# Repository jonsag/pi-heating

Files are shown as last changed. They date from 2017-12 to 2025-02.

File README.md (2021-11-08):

# pi-heating

Some scripts tweaked from https://github.com/JeffreyPowell, and many others created by me.  

Also there are CAD drawings and PCB layouts to build the electrical parts.  

Eventually you will have a Raspberry Pi that:

* controls (for example) a heater
* measures and logs your electric power consumption
* measures and logs numerous temperatures
* measures and logs wind direction and speed
* measures and logs rain
* presents it all via web GUI with some nice graphs
* also presents it on LCD displays
* can export logs to (spreadsheet or) csv

Let's start it all by

## Installing OS

Download 'Raspberry Pi OS Lite' from [https://www.raspberrypi.com/software/operating-systems/](https://www.raspberrypi.com/software/operating-systems/)  

Cd to where your download is and unpack it  
>$ unzip *-raspios-buster-armhf-lite.zip  

Insert SD-card and find out drive letter  
>$ dmesg  

For example /dev/mmcblk0 or /dev/sdb  

Unmount if mounted  
>$ umount /dev/mmcblk0p1  

Write image to SD-card  
>$ sudo dd bs=4M if=<version\>-raspios-buster-armhf-lite.img of=/dev/<device\> conv=fsync status=progress  

    1870659584 bytes (1,9 GB, 1,7 GiB) copied, 105 s, 17,8 MB/s  
    447+0 records in  
    447+0 records out  
    1874853888 bytes (1,9 GB, 1,7 GiB) copied, 139,716 s, 13,4 MB/s  

Remove SD-card and insert it again to make new partitions visible  

Mount the first partition  
>$ sudo mount /dev/<device\>1 /mnt/tmp  

Write empty file to boot partition to enable ssh at boot  
>$ sudo touch /mnt/tmp/ssh  

Remove SD-card and insert it in a RPi connected to your local network and boot it up  

## RPi configuration

### How to find RPi's IP

If you can't locate the IP, here's a little tutorial  

First find your subnet  
>$ ip -o -f inet addr show | awk '/scope global/ {print $4}'  

You will get something like  

    192.168.10.39/24  

where the first of is your ip, and the second is the netmask  

Now scan your local network for hosts  
>$ nmap -snP 192.168.10.0/24  

where the first is your subnet, and the last is the netmask  
Try to figure out which is your RPi from the output  

### How to connect without ssh password (optional)

If you haven't already, create a keypair  
>$ ssh-keygen ~/.ssh/id_rsa  

Copy the public key to RPi  
>$ ssh-copy-id -i ~/.ssh/id_rsa.pub pi@<IP\>  

### Connect and configure

>$ ssh <IP\> -l pi  

Login with user: pi and password:raspberry  

Update  
>$ sudo apt-get update && sudo apt-get upgrade && sudo apt autoremove  

Configure  
>$ sudo raspi-config  

* 1 S3 Change password  
* 1 S4 Change hostname  
* 3 P7 Enable 1-wire at boot  
* 4 P2 Set GPU memory to 16  
* 5 L1 Set locales (I chose en_GB.UTF-8 and sv_SE.UTF-8, setting en_GB.UTF-8 as default)  
* 5 L2 Set time zone  
* 5 L3 Choose keyboard layout (not necessary if you only connect by ssh)  
* 5 L4 Set wifi country  
* 6 A1 Expand file system to use whole SD-card  

Reboot to set new options  
>$ sudo reboot && exit  

Now it's time to:

## Download sources

Connect to the RPi again  
Install git, if you haven't already  
>$ sudo apt install git -y  

Make sure you're in pi's home directory  
>$ cd /home/pi  

Download source files  
>$ git clone [https://github.com/jonsag/pi-heating.git](https://github.com/jonsag/pi-heating.git)  

## Installation

Go to the newly downloaded directory  

>$ cd pi-heating

and run the install script  

>$ sudo ./install.sh  

The script will ask you many questions, and you will have some options on each:  

* Click enter to accept the default 'yes'  
* Enter 'n' or 'N' to decline  
* Enter 'h' or 'H' to view the help explanation  

Also you will have to answer some questions during the installs themselves, especially when MariaDB is installed.  

## Post install setup

## piHeatingHub

In a browser, go to  

    http://<IP>:8080/status.php  

### Adding sensors

Click  

    Input Sensors

and then  

    Scan for new sensors

After scanning click  

    Done

### Adding devices

Click  

    Output Devices

Click  

    Add new

Click  

    Edit

on the new one just added.  
Fill in all the fields and then click  

    Save

and then  

    Done

twice.  

Note: Pin numbers are used, NOT GPIO numbers.  

If using the piHeatingLCD hat, the one output device is at GPIO15, pin 10, and it it active HIGH, so you would set H/L to 1.  
Follow further instructions under piHeatingLCD  

## piHeatingRemote

After connecting Dallas temperature sensors,  
find 1-wire devices serial numbers  

>$ ls /sys/bus/w1/devices/  

Edit  

    /home/pi/bin/piHeatingRemote/configs/sensors

and insert serials and names, for example  

    28-0516b4ff09ff = Out  

To see value  

>$ cat /sys/bus/w1/devices/28-0416c1ec26ff/w1_slave  

See how many devices added  

>$ curl localhost:8081/count.php && echo  

See names  

>$ curl localhost:8081/name.php?id=1 && echo  

change id=1 to id=2 etc  

See values  

>$ curl localhost:8081/value.php?id=1 && echo  

## piHeatingLCD

The LCD and buttons will work if:  

* you have a schedule that always keep a low temperature  
* you have a second schedule that pulls up the temperature at certain times  
* you have a single mode that pulls up the temperature  
* you have a single timer that pulls up the temperature  

Build according to files in  

    Documents/piHeatingLCD

### Web setup

In a browser, go to  

    http://<IP>:8080/status.php

Log in with user 'admin' and the password you set up during the hub installation.  

### Add sensor

Add the sensor that will measure the temperature that will be regulated.  

Click  

    Input Sensors
    Scan for new sensors

When sensor is found, click  

    Done

### Add devices

Add the device that will control the heater.  

Click  

    Output Devices

Click  

    Add new

Click  

    Edit

on the newly added device.  
Set  

    Name: <name>
    GPIO Pin: 10
    Pin Active H/L: <if you use the NO, then this should be 1>

Click  

    Save
    Done
    Done

### Add mode

This mode will pull up the temperature to the higher level indefinitely.  

Click  

    Modes
    Add new

Click  

    Edit

on the newly added mode, and set  

    Name: <name>

, for example 'Warm' to indicate it will be used to pull up the temperature.

Then click  

    Done

### Add timer

This timer will be used to pull up the temperature for a certain amount of time.  

Click  

    Timers
    Add new

Ón the newly created timer, click  

    Edit

Set  

    Name: <name for the timer, for example 'Warm 6 hrs'>
    Duration: <the duration the timer will be active, in minutes,for example '360'>

, then click  

    Save
    Done
    Done

### Add schedules

The first schedule will pull up the temperature once, or several times, a week.  

Click  

    Schedules
    Add new

Click  

    Edit

on the newly created schedule.  

Enter

    Name: <name, for example 'Weekly meeting'>
    Start time: <some time before the temperature must be reached>
    End time: <the time when the temperature can start dropping>
    Repeat schedule every: <the day in question>
    When sensors: <sensor created earlier> IS LESS THAN <the high temperature you want to maintain>
    AND Timers: <timer previously added> STOPPED
    Activate Devices:<mark the device you created before>
    AND Modes: <mode previously added> OFF

Click  

    Save
    Done

The second schedule will use the mode created earlier to pull up the temperature indefinitely  

Add another timer as before and enter

    Name: <name, for example 'Warm'>
    Start time: 00:00:00
    End time: 23:59:59
    Repeat schedule every: <mark all weekdays>
    When sensors:  <sensor created earlier> IS LESS THAN <the high temperature you want to maintain>
    AND Timers: <timer previously added> (IS IGNORED)
    Activate Devices: <mark the device you created before>
    AND Modes: <mode previously added> ON

Click  

    Save
    Done

The third schedule will use the timer created earlier to pull up the temperature the time set  

Add another timer as before and enter

    Name: <name, for example 'Warm, 6 hrs'>
    Start time: 00:00:00
    End time: 23:59:59
    Repeat schedule every: <mark all weekdays>
    When sensors:  <sensor created earlier> IS LESS THAN <the high temperature you want to maintain>
    AND Timers: <timer previously added> RUNNING
    Activate Devices: <mark the device you created before>
    AND Modes: <mode previously added> (IS IGNORED)

Click  

    Save
    Done

The fourth, and last, schedule will keep the temperature low at all other times

Add another schedule as before and enter

    Name: <name, for example 'Cold'>
    Start time: 00:00:00
    End time: 23:59:59
    Repeat schedule every: <mark all weekdays>
    When sensors: <sensor created earlier> IS LESS THAN <the low temperature you want to maintain>
    AND Timers: <timer previously added> STOPPED
    Activate Devices: <mark the device you created before>
    AND Modes: <mode previously added> OFF

Click  

    Save
    Done
    Done

### Resources

Calculate burden resistor for your current clamp

>$ python resistor.py \<resistance\> \<tolerance\>  

### Usage

The LCD screen stays dark, unless pressing a button.  

* Button 1: Shows status  
* Button 2: Toggles mode, heats indefinitely  
* Button 3: Toggles timer, heats for set time  
* Button 4: Cancels both mode and timer  

### Note

If you install on Raspberry Pi rev 1, you must edit  

    piHeatingLCD/config.ini

Change line from  

    lcd_d6        = 27

to  

    lcd_d6        = 21

## piPowerTempLog

Build according to files in  

    Documents/ardPowerTempLog

This build requires an ethernet shield.  

## piWeatherLog

Build according to files in  

    Documents/ardWeatherLog

Connect the Arduino Weather Sensor to RPi  

Find out tty-device  

>$ dmesg | grep tty  

Probably named something like '/dev/ttyACM0'  
If not, edit  

    /var/www/piWeatherLog/weather.php  

Change line  

    $serial->deviceSet("/dev/ttyACM0");  

In file  

    /home/pi/bin/piWeatherLog/cron/bootWrapper.sh  

change lines  

    stty -F /dev/ttyACM0 cs8 9600 ign...  

and  

    screen -d -m -S init /dev/ttyACM0 9600

so it matches the output from dmesg command  

## The electrical builds

For all electrical builds there are CAD files for each project under 'Documentation'.  
Not all have finished PCB etch masks available as pdf.  
If you like to make some yourself, install KiCad ([https://www.kicad.org](https://www.kicad.org)) and just make them.  
I have made all as single layer PCBs myself, but just go ahead and route some double layered ones.  
If you don't want to make them them yourself, I can recommend JLCPCB ([https://jlcpcb.com](https://jlcpcb.com)), reasonably fast and very cheap.  

### piHeatingLCD

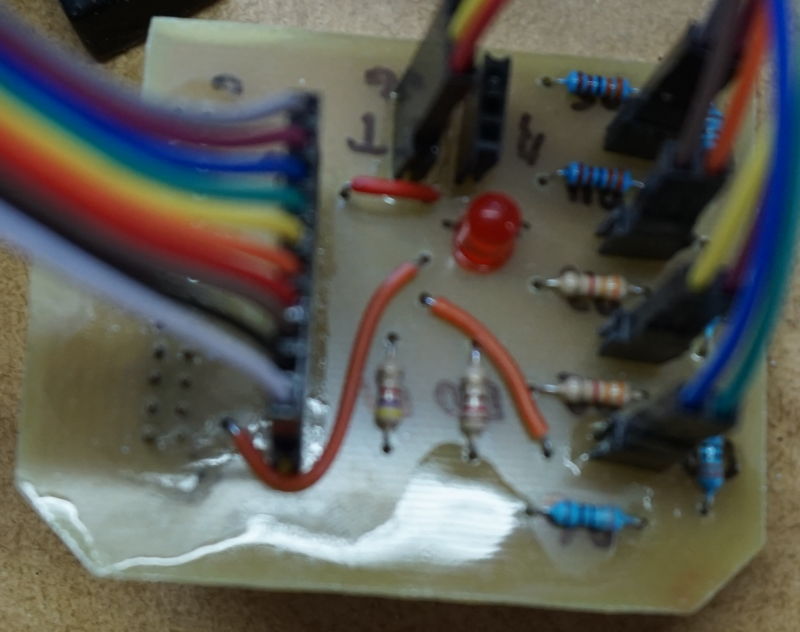
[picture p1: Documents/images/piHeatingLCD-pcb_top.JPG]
piHeatingLCD PCB top view


### ardPowerTempLog

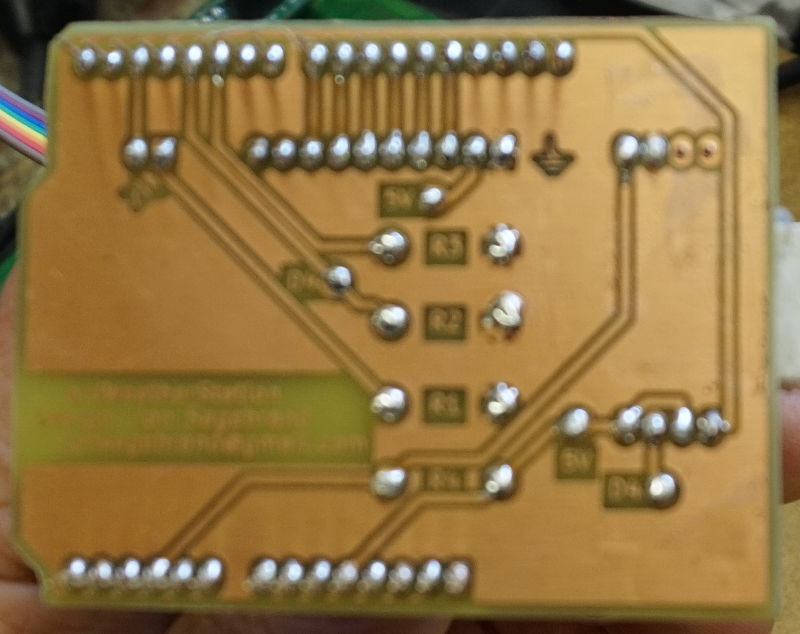
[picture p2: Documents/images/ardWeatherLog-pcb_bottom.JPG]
testing ardPowerTempLog PCB bottom view
  

This build also require some current clamps.  

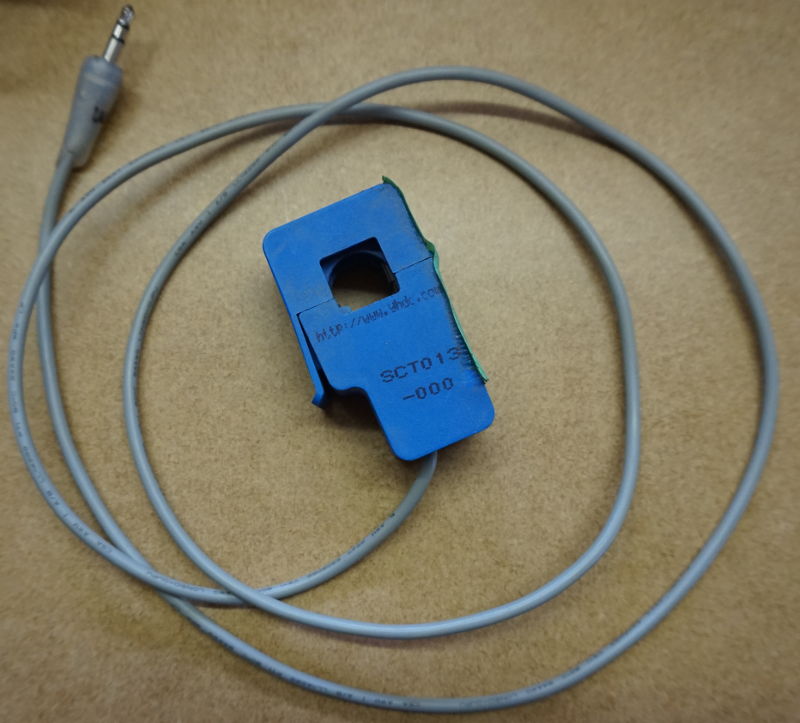
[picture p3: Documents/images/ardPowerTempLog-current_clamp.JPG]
ardPowerTempLog current clamp
  

I use three of these.  
If you go with other ones you will have to adapt your resistor values accordingly.  

Also, of course, you will need some DS18B20 1-wire temperature sensors.  

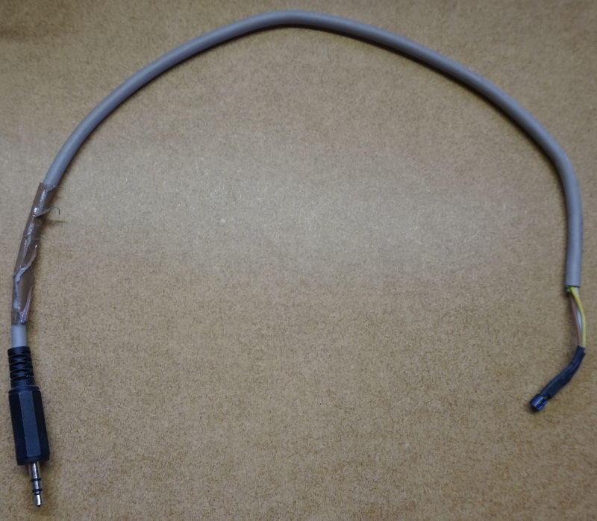
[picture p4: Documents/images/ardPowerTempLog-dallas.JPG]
ard>PowerTempLog temp sensor
  

Other ones will also do, but then check what library and settings you use in the Arduino sketch.  
I have soldered cables directly to the pins, and connected it to a phono plug.  

Then you will need some device to catch the blinks on your power meter.  

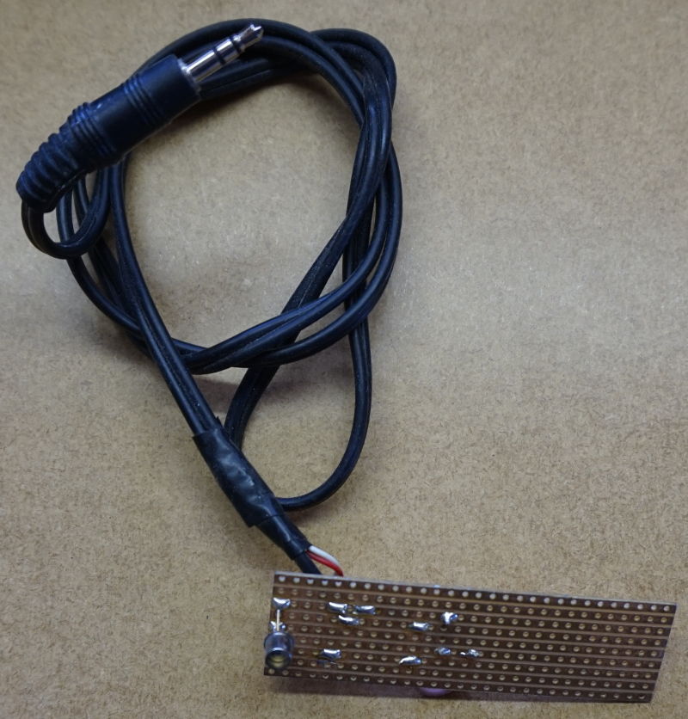
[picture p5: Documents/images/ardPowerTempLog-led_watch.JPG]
ardPowerLog LED watch
  

### ardWeatherLog

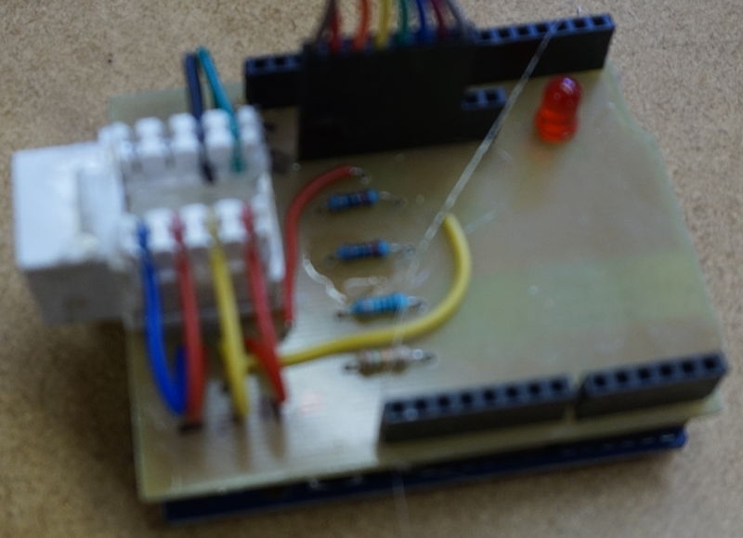
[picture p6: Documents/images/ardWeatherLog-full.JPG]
ardWeatherLog full
  

I use an ordinary ethernet cable to connect the Arduino to the weather sensors.  

The sensors are some devices I got from a cheap weather station.  
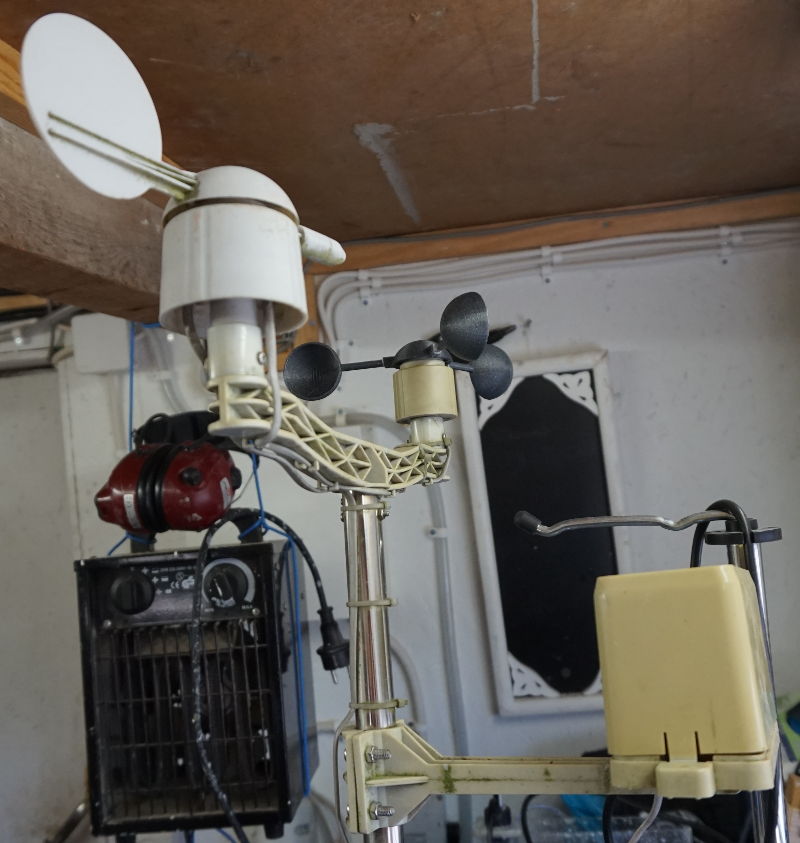
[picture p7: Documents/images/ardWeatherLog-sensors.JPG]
ardWeatherLog sensors
  
I just tossed the LCD that went with it.  

## Install Arduino IDE

Install Arduino IDE from [https://www.arduino.cc/en/Main/Software](https://www.arduino.cc/en/Main/Software)  

>$ mv arduino-*.tar.xz ~/bin  
>$ cd ~/bin  
>$ tar -xvJf arduino-*.tar.xz  
>$ cd arduino-*  
>$ ./install.sh  

## Install Average library

Copy directory Average to your Arduino/libraries directory  

## Quick reference

### What is installed and where

Executables installed in  

    /home/pi/bin

Web GUI installed in  

    /var/www

Apache site configurations in  

    /etc/apache2/sites-enabled/

Apache listen directives in  

    /etc/apache2/ports.conf

Gpio service installed at  

    /lib/systemd/system/gpio.service

Extended boot parameters in  

    /boot/config.txt

Database at  

    /var/lib/mysql/piHeatingDB

Cron jobs in  

    /etc/cron.d/piHeating
    /etc/cron.d/piPowerTempLog

### Notes

piHeatingHub  

* executables installs in /home/pi/bin/piHeatingHub  
* www installs in /var/www/piHeatingHub  
* runs on port 8080  
* mysql setup creates password, and stores credentials /home/pi/bin/piHeatingHub/config/config.ini  
* secure install creates password for user 'admin', and stores it in /home/pi/bin/piHeatingHub/.htpasswd  
* runs cron job at /home/pi/bin/piHeatingHub/cron/wrapper.sh every minute  

piHeatingRemote  

* executables installs in /home/pi/bin/piHeatingRemote  
* www installs in /var/www/piHeatingRemote  
* runs on port 8081

piHeatingLCD  

* executables installs in /home/pi/bin/piHeatingLCD  
* requires gpio-watch  
* requires Adafruit Char LCD

piPowerTempLog  

* executables installs in /home/pi/bin/piPowerTempLog  
* www installs in /var/www/piPowerTempLog  
* runs on port 8082
* runs cron job at /home/pi/bin/piPowerTempLog/cron/wrapper.sh every 2 minutes  

piWeatherLog  

* executables installs in /home/pi/bin/piWeatherLog  
* www installs in /var/www/piWeatherLog  
* runs on port 8083
* runs cron job at /home/pi/bin/piWeatherLog/cron/wrapper.sh every 2 minutes  

### URLs

Hub:  
Pi heating hub status page: http://\<IP\>:8080/status.php  

Remote:  
Sensors count: http://\<IP\>:8081/count.php  
Sensor name for sensor #1: http://\<IP\>:8081/name.php?id=1  
Sensor value for sensor #1: http://\<IP\>:8081/value.php?id=1

Power log:  
Main page: http://\<IP\>:8082  

Weather log:  
Main page: http://\<IP\>:8083/weather.php

## Testing  

Below is only for my testing during development  
Use with caution!  

Upload source  

>$ rsync -avz --delete . pi@192.168.10.52:pi-heating/  

Upload piPowerTempLog www  

>$ rsync -avz . pi@192.168.10.52:/var/www/piPowerTempLog && ssh pi@192.168.10.52 "sudo chown pi:www-data /var/www/piPowerTempLog -R && sudo chmod 755 /var/www/piPowerTempLog/*.php"  

Upload piHeatingHub www  

>$ rsync -avz . pi@192.168.10.52:/var/www/piHeatingHub && ssh pi@192.168.10.52 "sudo chown pi:www-data /var/www/piHeatingHub -R && sudo chmod 755 /var/www/piHeatingHub/*.php"  

### On hub

View gpio.service  

>$ cat /lib/systemd/system/gpio.service  

View gpio script  

>$ cat /home/pi/bin/piHeatingLCD/gpio-scripts  

View gpio-watch log  

>$ tail -f ~/bin/piHeatingLCD/gpio-watch.log  

Test LCD  

>$ /home/pi/bin/piHeatingLCD/print-to-lcd.py -1 test1 -2 test2  

Simulate Button 1 press  

View config file  

>$ cat /home/pi/bin/piHeatingHub/config/config.ini  

Login to database  

>$ mysql -u pi -p$(cat /home/pi/bin/piHeatingHub/config/config.ini | grep password | awk '{ print $3 }') piHeatingDB  

using password from the above config  

Change ip on sensor  

>$ UPDATE sensors SET ip = 'new ip' WHERE ip = 'old ip';  

Set values for tty communications  

>$ stty -F /dev/ttyACM0 cs8 9600 ignbrk -brkint -imaxbel -opost -onlcr -isig -icanon -iexten -echo -echoe -echok -echoctl -echoke noflsh -ixon -crtscts

### On remote

Show sensor ids  

>$ ls /sys/bus/w1/devices/  

### Check Arduino output

Connect to arduino with screen:  

>$ screen /dev/ttyACM0 9600 -S \<session name>  

To get screen command prompt, enter  
[C-a] :  
Then type

    quit  

and [Return]  

or from outside of screen  

>$ screen -XS \<session name> quit  

Kill screen with ^ak or control-a k

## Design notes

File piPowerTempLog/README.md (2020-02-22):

piPowerTempLog  

A sub project to monitor power and temperatures  

Installing OS
=============================
Download Raspbian Stretch Lite from https://www.raspberrypi.org/downloads/raspbian/  
Choose the Light zip-file  

Cd to where your download is  
>$ unzip 2020-02-13-raspbian-buster-lite.zip  

Insert SD-card and find out drive letter  
>$ dmesg  

For example /dev/mmcblk0 or /dev/sdb  

Unmount if mounted  
>$ umount /dev/mmcblk0p1  

Write image to SD-card  
>$ sudo dd bs=4M if=2020-02-13-raspbian-buster-lite.img of=/dev/mmcblk0 conv=fsync status=progress 

Remove SD-card and insert it again to make new partitons visible     

Mount the first partition  
>$ sudo mount /dev/mmcblk0p1 /mnt/tmp  

Write empty file to boot partition to enable ssh at boot  
>$ sudo touch /mnt/tmp/ssh  

Remove SD-card and insert it a Rpi connected to your local network and boot it up  

Rpi configuration
-----------------------------
Connect to Rpi via ssh  
Login with user: pi and password:raspberry 

Update  
>$ sudo apt-get update && sudo apt-get upgrade  

Configure  
>$ sudo raspi-config   

1		Change password  
2 N1	Change hostname  
4 T1	Set locales  
4 T2	Set time zone  
4 T3	Choose keyboard layout    
4 T4	Set wifi country  
5 P7	Enable 1-wire at boot  
7 A1	Expand file system to use whole SD-card  
7 A3	Set memory split to 16  

Reboot to set new options  

Install LAMP
==========
Install packages  
>$ sudo apt install apache2 apache2-utils mariadb-server mariadb-client php php-mysql libapache2-mod-php php-common php-cli php-json php-readline

Check apache is running  
>$ systemctl status apache2

If not:
>$ sudo systemctl start apache2

>$ sudo systemctl enable apache2

Check MariaDB is running  
>$ systemctl status mariadb

If not:
>$ sudo systemctl start mariadb

>$ sudo systemctl enable mariadb

Run MariaDB post install script  
>$ sudo mysql_secure_installation

Set MariaDB root password  
Press 'enter'  to all remaining questions  

Test to connect to the db  
>$ sudo mysql -u root  

Enable the apache php mod  
>$ sudo a2enmod php7.3

Restart apache  
>$ sudo systemctl restart apache2

Test apache-php
----------
Create info.php in web root  
>$ sudo emacs /var/www/html/info.php

Put following in the file  

	<?php phpinfo(); ?>
	
Go to

	http://<raspberry pi's ip>/info.php
	
in a browser
	
Installation
==========
Install requisites
----------
>$ sudo apt install git rsync ttf-mscorefonts-installer

Other useful tools
----------
>$ sudo apt install emacs screen

Get source files
----------
>$ cd /home/pi  

>$ git clone https://github.com/jonsag/pi-heating.git  

>$ cd /home/pi/pi-heating/piPowerTempLog  

Setup database and user  
>$ sudo mysql -u root < database-setup.sql

Add tables to the new database  
>$ mysql -u arduino -parduinopass powerTempLog < tables-setup.sql

Copy contents of arduinolog to webroot  
>$ sudo cp -r piPowerTempLog /var/www/html/

Download calendar_localized and unzip it ( http://www.triconsole.com/php/calendar_datepicker.php)  
>$ sudo unzip calendar_localized* -d /var/www/html/piPowerTempLog/

Add symbolic links for fonts  
>$ cd /usr/share/fonts/truetype

>$ sudo ln -s msttcorefonts/arialbd.ttf arialbd.ttf

>$ sudo ln -s msttcorefonts/arial.ttf arial.ttf

Change ownership  
>$ sudo chown www-data:www-data -R /var/www/html

Add a line to your crontab  
>$ crontab -e

Add the following:  

	*/2 * * * * /usr/bin/php /var/www/html/piPowerTempLog/powerPoller.php 0 1 cron > /dev/null 2>&1
	*/2 * * * * /usr/bin/php /var/www/html/piPowerTempLog/tempPoller.php 0 1 cron > /dev/null 2>&1

Host settings
----------
Make sure your /etc/hosts has an entry for the arduino, for example:  

	192.168.10.10   arduino01

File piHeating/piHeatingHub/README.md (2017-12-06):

# pi-heating-controller

jffrypwll @ googlemail.com

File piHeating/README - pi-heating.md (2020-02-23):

piHeating  

Some scripts tweaked from https://github.com/JeffreyPowell  

Installing OS
=============================
Download Raspbian Stretch Lite from https://www.raspberrypi.org/downloads/raspbian/  
Choose the Light zip-file  

Cd to where your download is  
>$ unzip 2017-11-29-raspbian-stretch-lite.zip  

Insert SD-card and find out drive letter  
>$ dmesg  

For example /dev/mmcblk0 or /dev/sdb  

Unmount if mounted  
>$ umount /dev/mmcblk0p1  

Write image to SD-card  
>$ sudo dd bs=4M if=2017-11-29-raspbian-stretch-lite.img of=/dev/mmcblk0 conv=fsync status=progress 

Remove SD-card and insert it again to make new partitons visible     

Mount the first partition  
>$ sudo mount /dev/mmcblk0p1 /mnt/tmp  

Write empty file to boot partition to enable ssh at boot  
>$ sudo touch /mnt/tmp/ssh  

Remove SD-card and insert it a Rpi connected to your local network and boot it up 

Rpi configuration
-----------------------------
Connect to Rpi via ssh  
Login with user: pi and password:raspberry 

Update  
>$ sudo apt-get update && sudo apt-get upgrade  

Configure  
>$ sudo raspi-config   

1		Change password  
2 N1	Change hostname  
3 T1	Set locales  
3 T2	Set time zone  
3 T3	Choose keyboard layout    
3 T4	Set wifi country  
5 P7	Enable 1-wire at boot  
7 A1	Expand file system to use whole SD-card  
7 A3	Set memory split to 16  

Reboot to set new options  

Install prerequisites
-----------------------------
>$ sudo apt-get install git  

Installation
=============================
Get piHeating
----------
>$ cd /home/pi  

>$ git clone https://github.com/jonsag/pi-heating.git  

>$ cd /home/pi/pi-heating/piHeating  

On pi running as hub or hub/remote:
-----------------------------
>$ sudo ./pi-heating-hub-install.sh  

Initialize mysql  
>$ sudo mysql -u root -p  

Use the same password as pi login  
Quit with exit  

>$ sudo ./pi-heating-hub-mysql-setup.sh  

>$ sudo ./pi-heating-hub-secure.sh  

Hook up relay to hub:
-----------------------------
Pin 2 - GPIO +5V to relay +  
Pin 14 - GPIO GND to relay GND  
Pin 10 - GPIO 15 to heating relay signal  

On pi running solely as remote or as hub/remote:
-----------------------------
>$ sudo ./pi-heating-remote-install.sh  

Hook up 1-wire temp sensors to remote:
-----------------------------
Pin 1 - GPIO 3,3V to 1-wire power  
Pin 6 - GPIO GND to 1-wire GND  
Pin 7 - GPIO 4 to 1-wire signal  
Connect 4,7k resistor between power and signal  

Find 1-wire devices serial numbers  
>$ ls /sys/bus/w1/devices/  

Edit /home/pi/pi-heating-remote/configs/sensors and insert serials and names, for example  
28-0516b4ff09ff = Out  

To see value  
>$ cat /sys/bus/w1/devices/28-0416c1ec26ff/w1_slave  

See how many devices added  
>$ curl localhost:8081/count.php && echo  

See names  
>$ curl localhost:8081/name.php?id=1 && echo  

change id=1 to id=2 etc  

See values  
>$ curl localhost:8081/value.php?id=1 && echo  

If using LCD:
=============================
The LCD and buttons will work if:  
* you have a schedule that always keep a low temperature  
* you have a single mode that pulls up the temperature  
* you have a single timer that pulls up the temperature  

>$ sudo ./pi-heating-LCD-install.sh  

>$ sudo apt-get install python-dev python-setuptools build-essential python-smbus  

>$ sudo easy_install -U distribute  

>$ sudo apt-get install python-pip  

>$ sudo pip install rpi.gpio  

Install Adafruit_Python_CharLCD python module by Adafruit from https://github.com/adafruit/Adafruit_Python_CharLCD.git  
>$ cd /home/pi/pi-heating/Resources/Adafruit_Python_CharLCD  

>$ sudo python setup.py install  

Install gpio-watch by larsks from https://github.com/larsks/gpio-watch  
>$ cd /home/pi/pi-heating/Resources/gpio-watch  

>$ make  

>$ sudo make install  

Hook up LCD and buttons:
-----------------------------
Pin 34 - GPIO GND 	LCD pin 1 GND  
Pin  2 - GPIO +5V 	LCD pin 2 VCC  
					LCD pin 3 CONTR - brightness control  
Pin 38 - GPIO 20  	LCD pin 4 RS  
             GND  	LCD pin 5 R/W  
Pin 40 - GPIO 21  	LCD pin 6 E  
Pin 31 - GPIO  6  	LCD pin 11 D4  
Pin 33 - GPIO 13  	LCD pin 12 D5  
Pin 35 - GPIO 19  	LCD pin 13 D6  
Pin 37 - GPIO 26  	LCD pin 14 D7  
Pin 17 - GPIO +3,3V LCD pin 15 N_C1 - backlight  
Pin 29 - GPIO 5		LCD pin 16 N_C2 - backlight on/off  
Pin 23 - button 1  

URLs:
==========
On remote:  
Sensors count: IP:8081/count.php  
Sensor name for sensor #1: IP:8081/name.php?id=1  
Sensor value for sensor #1: IP:8081/value.php?id=1

On hub:  
Pi heating hub: IP:8080/status.php  

Testing:  
=============================
Below is only for testing purpose  
Use with caution!  

On hub:  
Test LCD: $HOME/pi-heating-LCD/print-to-lcd.py -1 test1 -2 test2  
View config file: cat $HOME/pi-heating-hub/config/config.ini
Login to database: mysql -u pi -ppassword pi_heating_db (using password from the above config)  
Change ip on sensor: UPDATE sensors SET ip = 'new ip' WHERE ip = 'old ip';  

On remote:  
Show sensor ids: ls /sys/bus/w1/devices/

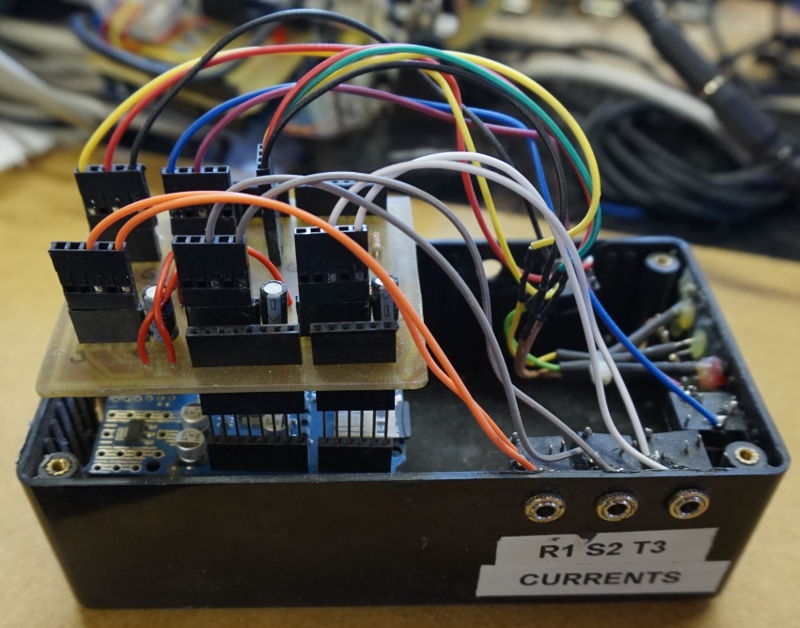
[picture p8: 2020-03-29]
Documents/images/ardPowerTempLog-full.JPG

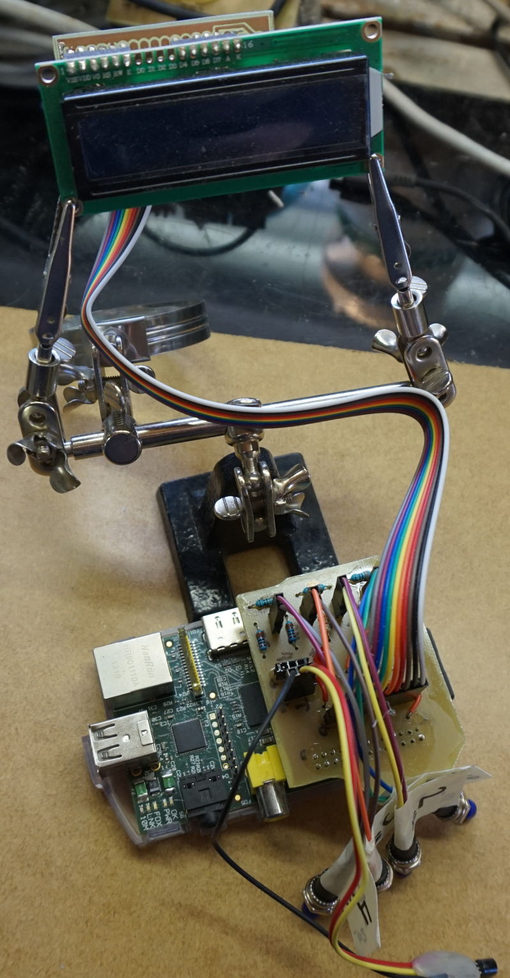
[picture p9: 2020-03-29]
Documents/images/piHeatingLCD-full.JPG

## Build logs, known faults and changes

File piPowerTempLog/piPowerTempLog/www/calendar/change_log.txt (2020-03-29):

//*****************************************
The php calendar component
written by TJ @triconsole
//*****************************************
Localization version & support by ciprianmp
- it includes all the updates/fixes in the
corresponding version of the original class
//*****************************************

//*****************************************
version 3.75-loc (07 January 2017)
//*****************************************
updated: Date.prototype function in calendar.js
	- thanks ciprianmp

fixed a bug which caused a strange behaviour for date 30 when there is no selection (selectable but warned as disabled even when not, disabled in dropdowns and an empty tooltip showing up)
	- thanks Tri

fixed a bug which allowed negative values to be sent from outside the class (probably by code injection/hacking attempts)
	- thanks Tri

fixed a layout bug when show_fb_info is set to false
	- thanks ciprianmp

fixed: check_internet_connection() script
	- thanks ciprianmp

add on: Uzbek language added
	- thanks Akbar Mirsidikov

fixed: tc_date and tc_date_main classes for broader php compatibility
	- thanks ciprianmp

add on: Finish language added
	- thanks Ilja Mäki

add on: Lithuanian language added
	- thanks Martynas Vanagas

add on: automatic read of available themes
	- thanks ciprianmp

updated: Date.prototype function in calendar.js
	- thanks ciprianmp

add on: calendar theme ('theme1', 'theme2', 'theme3') - function setTheme(theme_name)
	- thanks Tri

add on: buffer calendar output for print on screen later - function getScript()
	- thanks Tri

fixed: calendar auto hide glitch on Internet Explorer and Opera browser
	- thanks Sébastien

fixed: javascript split array support for Safari
	- thanks Tri

add on: month dropdown options use colors to differentiate between month statuses (enabled/disabled)
	- thanks ciprianmp

add on: disabled months cannot be selected in month dropdown anymore (option disabled, less annoying)
	- thanks ciprianmp

add on: day dropdown options use colors to differentiate between day statuses (weekday enabled/disabled, weekday, weekend)
	- thanks ciprianmp

add on: disabled days cannot be selected in day dropdown anymore (option disabled, less annoying)
	- thanks ciprianmp

//*****************************************
version 3.74 (29 January 2015)
//*****************************************
add lang: "Server Timezone:"
	- thanks ciprianmp

updated: optimized and add functions to reduce parameter sending over calendar pages
	- thanks Tri

fixed: minor bug fixed, error on function checkSpecifyDate() and prevent date-allow input errors
	- thanks ciprianmp

fixed: checkdate() function generated an error on some php servers
	- thanks Tri

fixed: major bug fixed, for dropdown selection, only picked 2 values out of 3 (year null after selection)
	- thanks Tri and ciprianmp

//*****************************************
version 3.73 (7 October 2014)
//*****************************************
fixed: applied a Turkish fix for i vs I usage in function names php<5.5 on Linux bug (http://trac.roundcube.net/ticket/1485470)
	- thanks ciprianmp and Tri

add on: Timezone function
	- thanks Tri

updated: vulnerabilities update on REQUEST parameter
	- thanks Arvid V.

fixed: minor bugs fixed on unset calendar value
	- thanks Tri

fixed: tooltips are not displayed on Safari browser (windows)
	- thanks Larry

fixed: an error when choose day and month, and year dropdown to null (first item on dropdown)
	- thanks Marco

add on: an event colors specified on calendar.css, alternative to the tooltip icons or use both
	- thanks Larry

fixed: the year interval limitation (1970/2038) has been eliminated for the entire class (timestamps not used anymore)
	- thanks Tri

fixed: recursive tooltips can now be set outside the limited interval 1970-2037
	- thanks ciprianmp

add on: Tooltips function
	- thanks ciprianmp

//*****************************************
version 3.72 (25 July 2014)
//*****************************************
add on: automatic check for an updated version available
	- thanks Tri

add on: built the FB page of the class and embedded the Like action button in the About section
	- thanks ciprianmp

add on: About icon, credits & version info displayed on hovering the About icon
	- thanks Tri and ciprianmp

add on: implemented the setToolTips() function to display infos for any date on calendar form
	- thanks ciprianmp and TJ

fixed: checkdate() function generated an error on some php servers
	- thanks Tri

add on: implemented the genitive month names in date long formats, for languages that require that approach (CZ, GR, FI, PL, RU, SK, SR, UK)
	- thanks ciprianmp

add on: all digits are now converted into indic/arabic/thai versions, optionally
	- thanks ciprianmp

adjust: most images converted to gif for smaller sizes (except the pngs that need transparency)
	- thanks ciprianmp

fixed: Incorrect next month display show on 'February 2008'
	- thanks Neeraj Jain for bug report

fixed: Incorrect month comparable on calendar_form.php line 113
	- thanks Djenan Ganic, Ian Parsons, Jesse Davis for bug report

add on: date on calendar form change upon textbox in datepicker mode
add on: validate date enter from dropdown and textbox

fixed: Calendar path not valid when select date from dropdown
	- thanks yamba for bug report

adjust: add new function setWidth and deprecate getDayNum function

fixed: year combo box display not correct when extend its value
	- thanks Luiz Augusto for bug report

fixed on date and month value return that is not leading by '0'

adjust: change php short open tag (<?=) to normal tag (<?php)
	- thanks Michael Lynch

add on: getMonthNames() function to make custom month names on each language
	- thanks Jean-Francois Harrington

add on: button close on datepicker on the top-right corner of calendar
	- thanks denis

fixed: hide javascript alert when default date not defined
	- thanks jon-b

fixed: incorrect layout when select part of date
	- thanks simonzebu (I just got what you said :) )

fixed: not support date('N') for php version lower 5.0.1 so change to date('w') instead
	- thanks simonzebu, Kamil, greensilver for bug report
	- thanks Paul for the solution

add on: setHeight() function to set the height of iframe container of calendar
	- thanks Nolochemcial

add on: startMonday() function to set calendar display first day of week on Monday - deprecated since 3.61 and replaced by startDate()

fixed: don't display year when not in year interval

fixed: day combobox not update when select date from calendar
	- thanks ciprianmp

add on: disabledDay() function to let the calendar disabled on specified day
	- thanks Jim R.

fixed: total number of days startup incorrect
	- thanks Francois du Toit, ciprianmp

add on: setAlignment() and setDatePair() function
	- thanks ciprianmp and many guys guiding this :)

fixed: the header of calendar looks tight when day's header more than 2 characters, this can be adjusted by increasing width on calendar.css [#calendar-body td div { width: 15px; }]
	- thanks ciprianmp

add on: setSpecificDate() to enable or disable specific date
	- thanks ciprianmp, phillip, and Steve to suggest this

utilizing and cleaning up some codes on tc_calendar.php, calendar_form.php, and calendar.js
	- thanks Peter

added: 2 functions for php version that does not support json
	- thanks Steve

fixed: javascript error on datepair function on v3.50 and 3.51
	- thanks ciprianmp

fixed: writeYear bug from $date_allow1 & 2 must be changed to $time_allow1 & 2
	- thanks ciprianmp again :(

updated: setSpecificDate can be set month, year, and no recursive simultaneously
	- thanks ciprianmp, Steve

add on: setOnChange to handling javascript onChange event

fixed: dateAllow contains error on calendar_form.php
	- thanks matthijs

fixed: error on calendar.js function checkSpecifyDate
	- thanks Todd

fixed: the value of calendar is not restored when using back button on browser
	- thanks Nicolai

add on: add X as background of disabled days
	- thanks SanSar

fixed: 'Day' combobox contain no list dropdown when not call setDate() on initialization
	- thanks Fulin

fixed: Fixed display style still have the default value in case the date is disabled.
	- thanks ciprianmp

fixed: today date color disappear when date is disabled.
	- thanks ciprianmp

fixed: javascript error from IE compatible not support for JSON
	- thanks ciprianmp

adjusted: change the color of today date to green with border
	- thanks ciprianmp

adjusted: rearrange source code on calendar_form.php for future use

add on: showWeeks function
	- thanks Michael

add on: support for RTL (right-to-left output)
	- thanks ciprianmp

add on: startDate function and will be used instead of startMonday

changed: make the DatePair function selectable on any dates. Date-from must be before Date-to, and on the other hand, otherwise it will be reset
	- thanks Chris, Rickard, ciprianmp

fixed: incorrect parameter submited on javascript that caused an invalid date returned
	- thanks ciprianmp

fixed: date selected hilight error
	- thanks John

add on: auto hide calendar
	- thanks Wayne, Chris

add on: auto focus an overlapping calendar to the top

fixed: json checking function return error when server does not support for json
	- thanks strangeplant

fixed: javascript possible error on Date.parse
fixed: add on-change javascript in dropdown datepicker mode (missing previously)
	- thanks Alex

fixed: 1st and 31st are always disabled when running with php4
	- thanks dl

changed: use DateTime php class for php version >= 5.3.0 to support year 2038 and later

fixed: valid today date checked with date allow
	- thanks ciprianmp

updated: calendar.js on Date.prototype.format
	- thanks Haravikk

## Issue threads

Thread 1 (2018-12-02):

LCD not working

5ft24dave, 2018-12-02:
The LCD code isn't working.
I have gone through to ensure I have timers, modes, continuous schedules etc all set up.
The rest of the thermostat is working perfectly.
It never initializes the LCD (connections double and triple checked, Adafruit example scripts work to drive the display properly etc)
When triggering button 1, I receive the following:

2018-12-01 16:42:10 run_script:105 pin 11: event script exited with status = 1
Traceback (most recent call last):
  File "/home/pi/pi-heating-LCD/print-to-lcd.py", line 190, in <module>
    activeNow = process_schedules(cursor, cnx, timeNow, True, False)  # (cursor, cnx, timeNow, process, verbose)
  File "/home/pi/pi-heating-LCD/modules.py", line 533, in process_schedules
    'setPoint': setPoint,
UnboundLocalError: local variable 'setPoint' referenced before assignment
2018-12-01 16:44:09 run_script:105 pin 11: event script exited with status = 1

jonsag, 2018-12-02:
Don't have access to a machine right now.
Will try to look into it later.
/jon

5ft24dave, 2018-12-02:
No hurry,
Thank you!

⁣Sent from BlueMail

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

jonsag, 2018-12-03:
As far as I can tell it has something to do with the time not present.
Is your pi connected to the internet, ie a timeserver?
If not, you will have to either have it connected, at least at bootup, or connect a RTC, as I have done in another project: https://github.com/jonsag/piSchoolBell
I will try to look more into it.
/jon

5ft24dave, 2018-12-03:
It's connected to the internet and I have a DS3231 RTC on it.  Time is current.

⁣Sent from BlueMail

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

jonsag, 2018-12-19:
Managed to create this error now.
It happens when there is no sensor found on the IP stored in the database.
It occured when i gave the RPi a new IP-number.
A quick fix is to login to the database and change IP to the RPis current one, or perhaps to set it to localhost(127.0.0.1).
mysql> UPDATE sensors SET ip = 'new_ip' WHERE ip = 'old_ip';
/jon

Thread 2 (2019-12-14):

Cant find new sensor

winogregorio, 2019-12-14:
Thanks for turning this into a self-contained solution.  I had a few roadblocks along the way (requires stretch not latest buster, incorrect paths in a few instructions, etc) but with yours and JeffreyPowell's instructions, I was able to overcome them.  I am at the point where I scan for new sensors but the web page times out after about a minute with no new sensors found.  I edited the config file and the cat command of the device returns data.  I'll admit that I am pretty new to pi and it has been almost 2 decades since I've done anything close to this so maybe I am overlooking the obvious.  I hope you can provide the missing link.
Thanks,
Greg

jonsag, 2019-12-14:
Been a long time since I did anything in this project.
Where/what was the wrong paths? Please tell me so I can correct it.
From my memory I recall something about an issue I had with timing out when scanning for devices. As I can recall it had something to do with incorrect subnet.
I'll look into it right now.

jonsag, 2019-12-14:
Try running the following from cli:
`nmap -sP <your subnet> | grep report | grep -v router | rev | cut -d' ' -f 1 | rev | tr -d '()'`
<your subnet> could be for example 192.168.0.1/24
Does it find any clients?

Could you please explain your setup.
Are you running hub and remote, or combined hub/remote?

> I edited the config file and the cat command of the device returns data.
What config file and what cat command?

winogregorio, 2019-12-14:
Thanks so much for taking the time to reply.  I tried the command below and it returned

PST

-Pn

seconds

I recall reading something about the subnet problem in the original instructions but could not find 192.168.x.x referenced in the sensors-list file.  This is where others corrected the problem.  My setup is a Pi Zero W running on a 10.222.0.0/24 network.

The trouble I had with the instructions were under Hook up 1-wire temp sensors to remote:

“Edit /home/pi/pi-heating-remote/configs/sensors and insert serials and names, for example 28-0516b4ff09ff = Out”

should be

“Edit /home/pi/pi-heating/pi-heating-remote/configs/sensors and insert serials and names, for example 28-0516b4ff09ff = Out”

Also, there does not appear to be a web server running on 8081 yet the next lines refer to 8081 instead of 8080. When I use 8080 in the curl command I get a permission denied error.  When I try it from a emote web browser, I get file not found.

Thanks again for looking at this,

Greg

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

winogregorio, 2019-12-14:
I retried the nmap command because I just realized the output was not right.  It found all the devices on my 10.222.0.0/24 network.  However, my router is also connected to a 192.168.1.0 network via a VLAN.  I’m not sure that makes a difference.

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

winogregorio, 2019-12-14:
I forgot to add, hub and remote on one device.  The config file I edited was the sensors file with the sensor serial number and name.  When I cat /sys/bus/w1/devices/28-00000b886971/w1_slave it returns

6e 01 4b 46 7f ff 02 10 71 : crc=71 YES

6e 01 4b 46 7f ff 02 10 71 t=22875

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

jonsag, 2019-12-14:
Well, there's your problem.
Look into lines 169 and 171 in sensors-list.php to correct your problem.
Probably line 169 gets wrong subnet and continues to scan the wrong subnet and time outs.
One quick solution is to substitute '$subnet_cidr' on line 171 with '10.222.0.0/24' in your case.

There should actually be two servers running. The hub runs a server on port 8080 and the remote on 8081.
The file /etc/apache2/ports.conf should have two Listen-directives, 'Listen 8080' and 'Listen 8081', if you ran both pi-heating-hub-install.sh and pi-heating-remote-install.sh on the same machine.
If you correct the file manually, remember to restart apache afterwards.

I don't have this up and running anywhere, so I can't confirm any of this right now.

About the paths in the README,
actually the path for the 'sensors'-file should be as it says, as per line 118 in pi-heating-remote-install.sh.
The path to the 'sensors'-file referred to in the README will be there _after_ the install.

winogregorio, 2019-12-14:
SUCCESS!!! Thank you so much, again.  I ran pi-heating-remote-install.sh and the webserver is now running on 8081 as well as 8080.  The instructions were not clear on that.  In fact, I don't think they mentioned it.
I did not have to edit the sensors-list.php file.  It appears to get the subnet information from the interface.  Now all I need to do is figure out how to output in Fahrenheit instead of Celsius I can get to work building the rest of them
Thanks,
Greg

jonsag, 2019-12-14:
Great.
Why not start a little revolution and join the rest of the world using the more sensible celsius scale! :-)

winogregorio, 2019-12-14:
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

I'm fully on board with that.  It's the wife I'm trying to please LOL!

jonsag, 2019-12-15:
Oh.
I know how important that is...
Good luck with everything
/jon

jonsag, 2019-12-15:
Come to think of it now, perhaps the easiest way is to start with the file 'value.php' where in line 29 the value is calculated.
Add a line below that with something like:

`$value = ($value × 9/5) + 32;`

and then change every occurence of 'C' to 'F' in the web GUI

winogregorio, 2019-12-15:
Thanks!  I was working backward to that. I edited line 29 to add *(9/5)+32 at the end.  Seems to have worked to convert the output to F.

However, in an effort to delete the historical data which still had the C values, I deleted the sensor and added it back which increased the Sensor ID value by 1.  To test it, I deleted and added it back a second time and it increased again by 1.  It now reads 3.  Probably in a config file someplace.  Overall, this is a minor detail that seems to have no impact.  I probably will not bother to investigate further.

I can’t thank you enough for your time.

Greg

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

jonsag, 2019-12-15:
The numbering of the sensors is stored in the sql database on the hub.
Make sure to also change any references in other tables referring to the sensor table, should you decide to go ahead and edit it.

winogregorio, 2019-12-15:
That makes sense.  Thanks again.

Greg

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

Closed 2019-12-15.

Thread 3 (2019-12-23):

Questions

winogregorio, 2019-12-23:
Wondering how you handle compressor minimum run times and minimum restart delays.  Can't seem to wrap my head around where to modify the code.  Also wondering if you have tested the "connected device" function.  Does not seem to detect properly or at all.

jonsag, 2019-12-27:
I don't think there is a function for minimum run times anywhere, but perhaps I can do something about it...
I will have to get back to you on the other question as I am away at the moment.
I'll try to set up a machine when I get home.

winogregorio, 2019-12-27:
Some form of hysteresis would do the job.  In other words, have a set point you wish to maintain and a configurable turn on point slightly below that.   Needs to be configurable because hot water heating would be a much wider band than space heat.
Cascading or multi level conditions and multiple temperature probe comparison would be other great features.
Thanks again - Greg

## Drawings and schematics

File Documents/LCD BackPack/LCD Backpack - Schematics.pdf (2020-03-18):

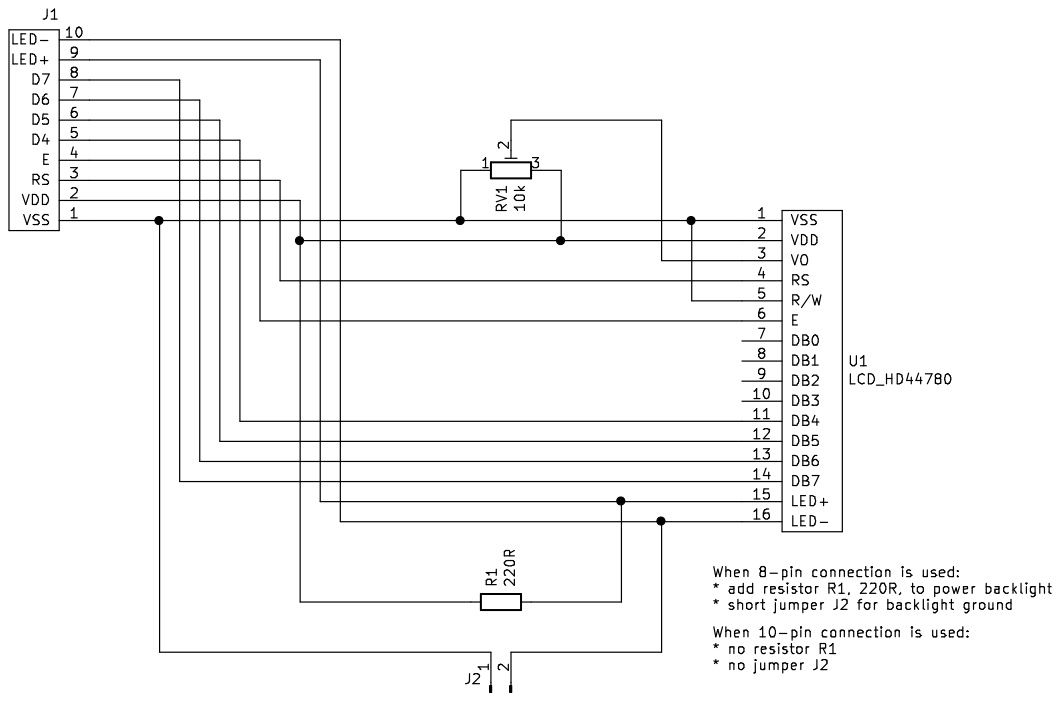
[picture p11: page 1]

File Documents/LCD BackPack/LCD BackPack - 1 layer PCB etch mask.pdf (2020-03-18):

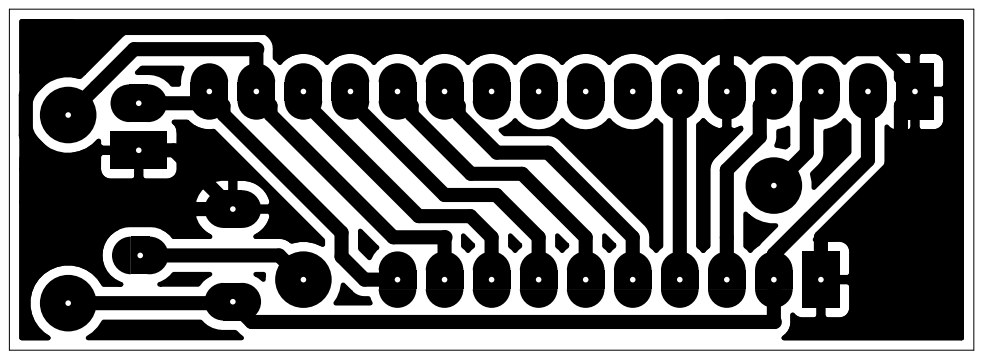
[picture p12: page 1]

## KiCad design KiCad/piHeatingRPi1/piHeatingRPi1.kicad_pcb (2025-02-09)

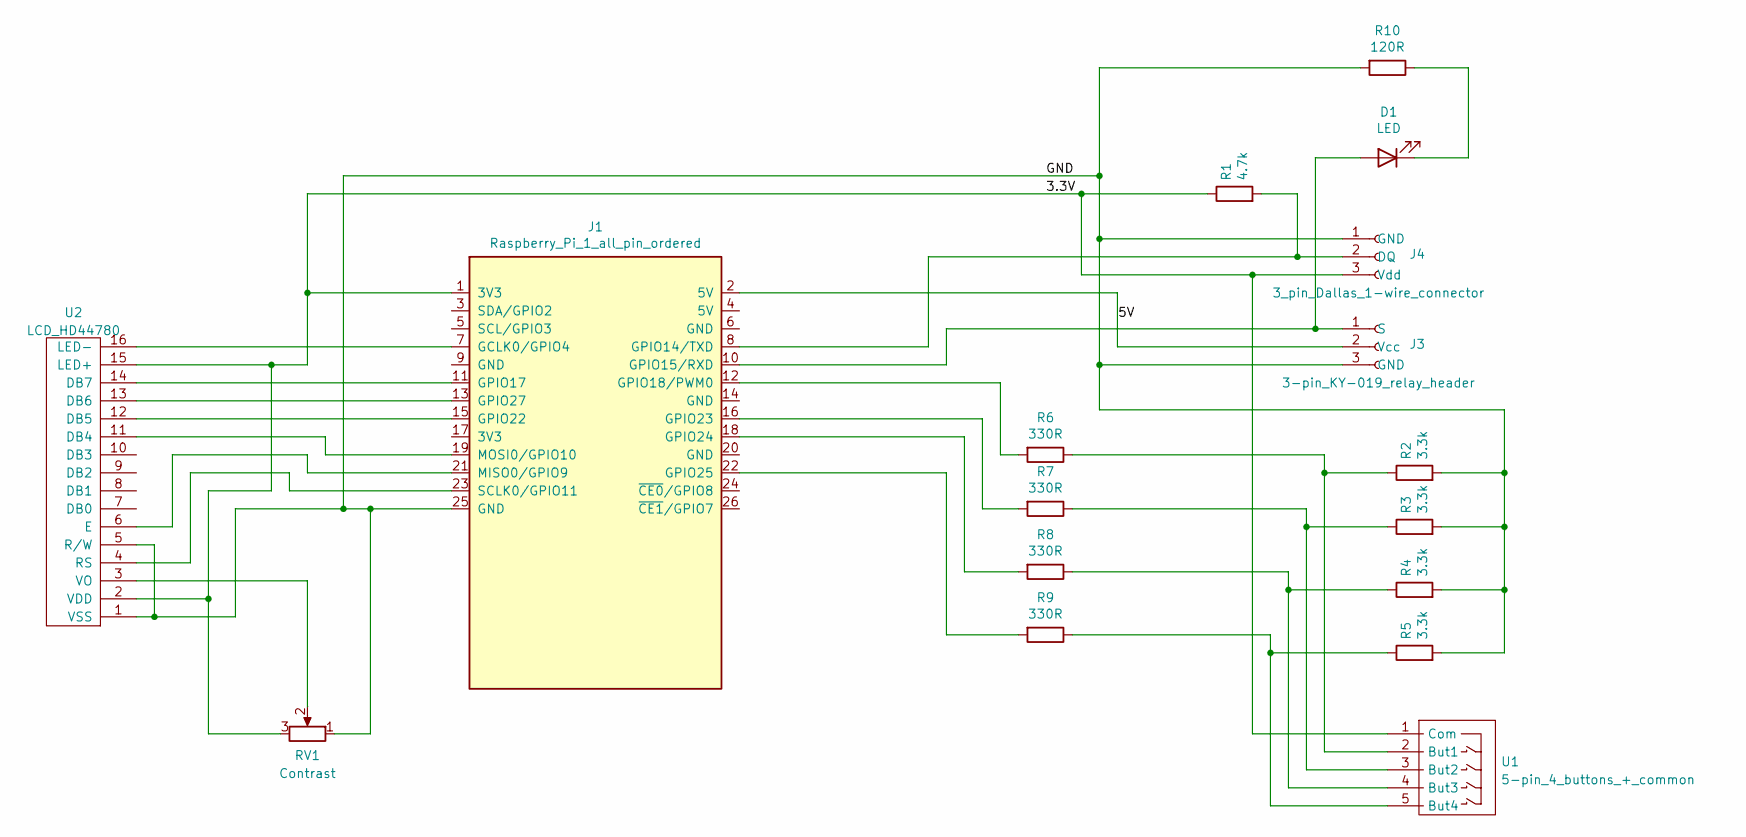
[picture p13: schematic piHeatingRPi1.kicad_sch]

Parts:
D1: LED; LED_D5.0mm_large
J1: Raspberry_Pi_1_all_pin_ordered; Raspberry_Pi_Hat_2x13_pin_GPIO_larger_pads
J3: 3-pin_KY-019_relay_header; 3-pin JST KY-019 relay
J4: 3_pin_Dallas_1-wire_connector; 3-pin JST DS18B20
R1: 4.7k; R_Axial_DIN0207_L6.3mm_D2.5mm_P10.16mm_Horizontal_larger_pa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
R2, R3, R4, R5: 3.3k; R_Axial_DIN0207_L6.3mm_D2.5mm_P10.16mm_Horizontal_larger_pa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
R6, R7, R8, R9: 330R; R_Axial_DIN0207_L6.3mm_D2.5mm_P10.16mm_Horizontal_larger_pa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
R10: 120R; R_Axial_DIN0207_L6.3mm_D2.5mm_P10.16mm_Horizontal_larger_pa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
RV1: Contrast; Potentiometer_Bourns_3339P_Vertical_large
U1: 5-pin_4_buttons_+_common; 5-pin JST 4 buttons + common
U2: LCD_HD44780; LCD_HD44780_16x2_w_headers_large

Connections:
/3.3V: J1.1 (3V3), J4.3 (Vdd), R1.1, RV1.3, U1.1 (Com), U2.2 (VDD), U2.15 (LED+)
/5V: J1.2 (5V), J3.2 (Vcc)
/GND: J1.25 (GND), J3.3 (GND), J4.1 (GND), R2.2, R3.2, R4.2, R5.2, R10.2, RV1.1, U2.1 (VSS), U2.5 (R/W)
unnamed: D1.1 (K), R10.1
unnamed: D1.2 (A), J1.10 (GPIO15/RXD), J3.1 (S)
unnamed: J1.7 (GCLK0/GPIO4), U2.16 (LED-)
unnamed: J1.8 (GPIO14/TXD), J4.2 (DQ), R1.2
unnamed: J1.11 (GPIO17), U2.14 (DB7)
unnamed: J1.12 (GPIO18/PWM0), R6.2
unnamed: J1.13 (GPIO27), U2.13 (DB6)
unnamed: J1.15 (GPIO22), U2.12 (DB5)
unnamed: J1.16 (GPIO23), R7.2
unnamed: J1.18 (GPIO24), R8.2
unnamed: J1.19 (MOSI0/GPIO10), U2.11 (DB4)
unnamed: J1.21 (MISO0/GPIO9), U2.6 (E)
unnamed: J1.22 (GPIO25), R9.2
unnamed: J1.23 (SCLK0/GPIO11), U2.4 (RS)
unnamed: R2.1, R6.1, U1.2 (But1)
unnamed: R3.1, R7.1, U1.3 (But2)
unnamed: R4.1, R8.1, U1.4 (But3)
unnamed: R5.1, R9.1, U1.5 (But4)
unnamed: RV1.2, U2.3 (VO)

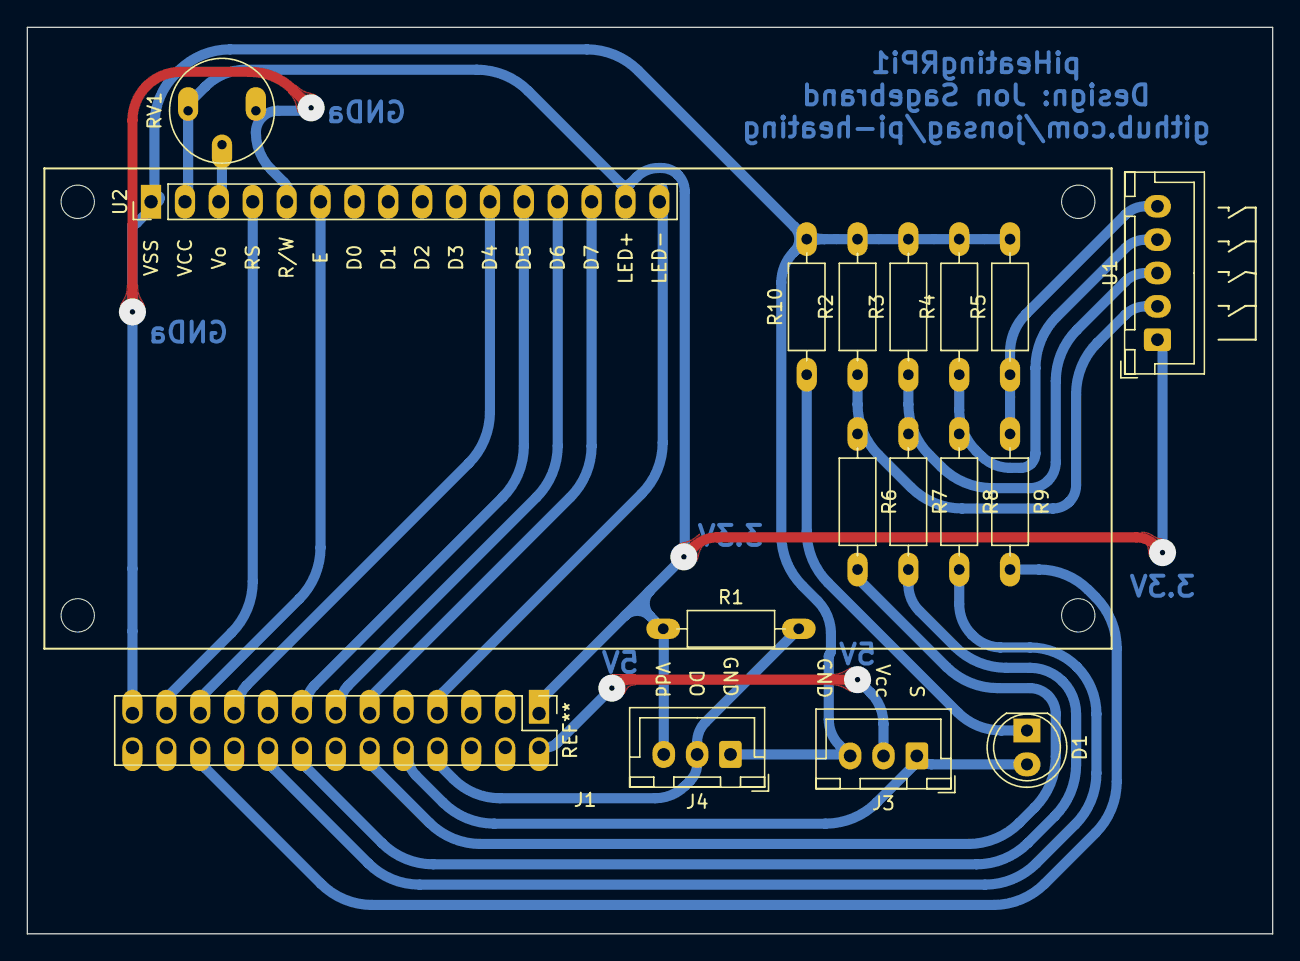
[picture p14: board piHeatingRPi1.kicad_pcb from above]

Board: 2 copper layers, 93.3 x 67.9 mm, 17 parts (0 on the bottom side), 22 nets.

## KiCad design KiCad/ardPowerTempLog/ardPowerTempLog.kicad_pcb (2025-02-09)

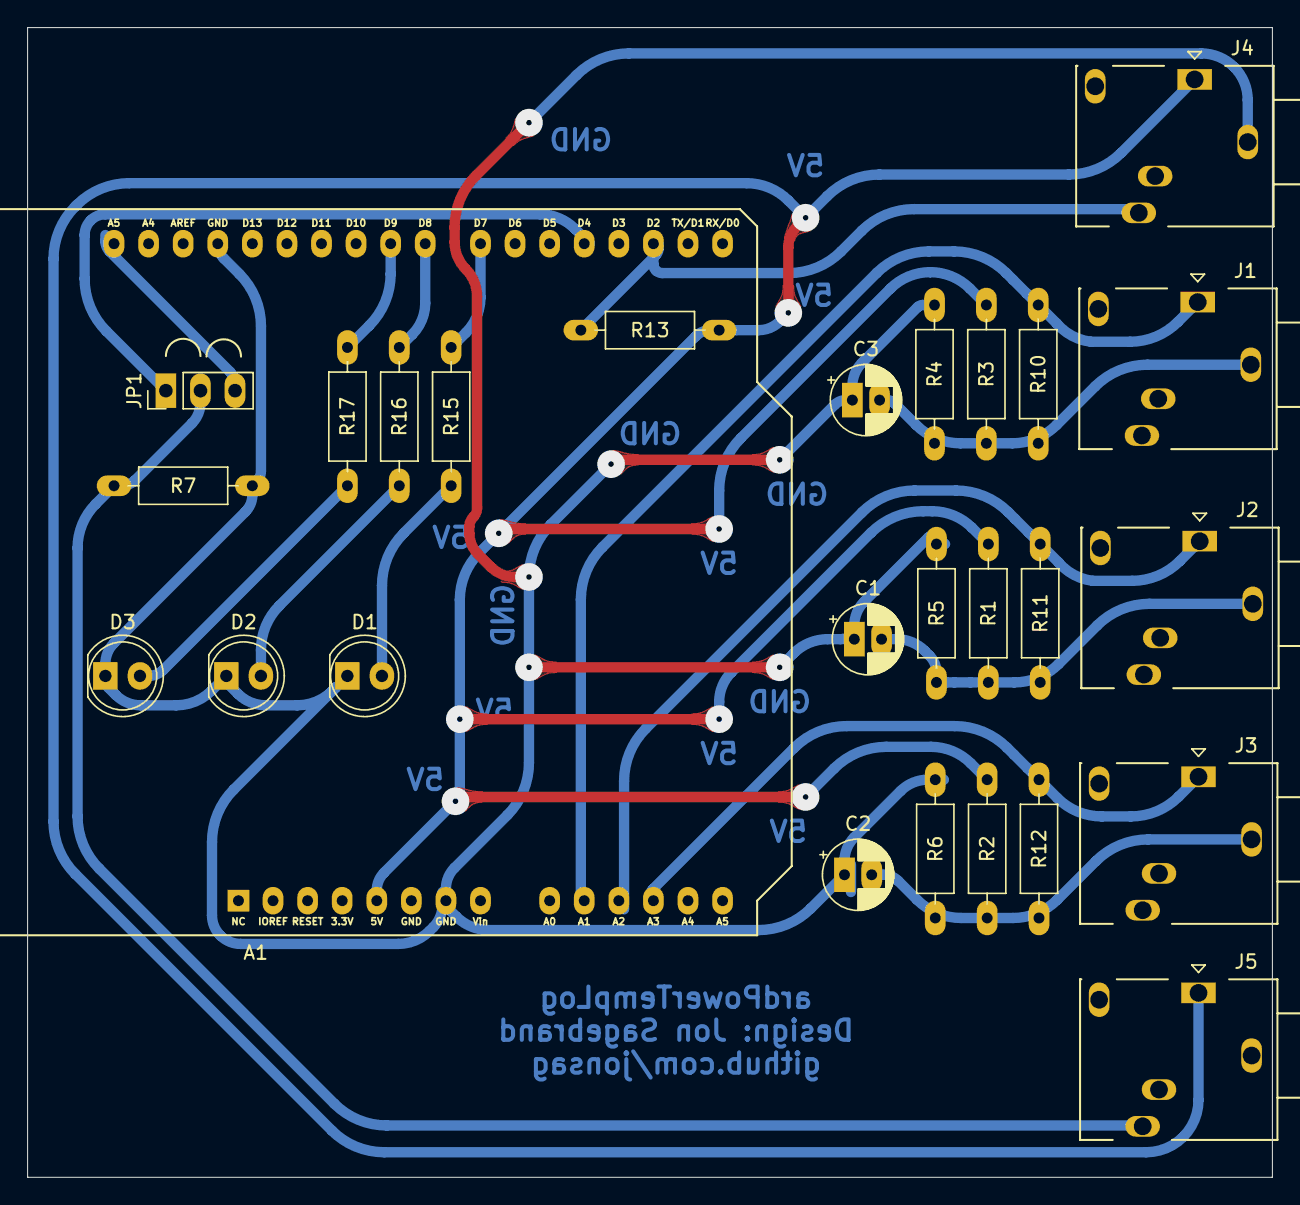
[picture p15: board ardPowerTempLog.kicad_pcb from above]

Board: 2 copper layers, 91.4 x 84.5 mm, 27 parts (0 on the bottom side), 18 nets.

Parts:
A1: Arduino_UNO_R3; Arduino_UNO_R3_shield_large
C1, C2, C3: 10u; CP_Radial_D5.0mm_P2.00mm_larger
D1: Status LED; LED_D5.0mm_large
D2: Polled LED; LED_D5.0mm_large
D3: Pulse LED; LED_D5.0mm_large
J1: R1; My_Jack_3.5mm_Ledino_KB3SPRS_Horizontal
J2: S2; My_Jack_3.5mm_Ledino_KB3SPRS_Horizontal
J3: T3; My_Jack_3.5mm_Ledino_KB3SPRS_Horizontal
J4: OneWire bus; My_Jack_3.5mm_Ledino_KB3SPRS_Horizontal
J5: LED sensor; My_Jack_3.5mm_Ledino_KB3SPRS_Horizontal
JP1: Analog/digital; Jumper_1x03_P2.54mm_large
R1, R2, R3, R4, R5, R6, R7: 10k; R_Axial_DIN0207_L6.3mm_D2.5mm_P10.16mm_Horizontal_larger_pa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
R10, R11, R12: 33R; R_Axial_DIN0207_L6.3mm_D2.5mm_P10.16mm_Horizontal_larger_pa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
R13: 4.7k; R_Axial_DIN0207_L6.3mm_D2.5mm_P10.16mm_Horizontal_larger_pa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
R15, R16, R17: 220R; R_Axial_DIN0207_L6.3mm_D2.5mm_P10.16mm_Horizontal_larger_pa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

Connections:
/Collector: A1.5 (+5V), J4.T, J5.T, R1.1, R2.1, R3.1, R13.2
/Data: A1.17 (D2), J4.S, R13.1
/Emitter: J5.S, JP1.2 (C), R7.2
/GND: A1.7 (GND), A1.29 (GND), C1.1, C2.1, C3.1, D1.1 (K), D2.1 (K), D3.1 (K), J4.G, R4.2, R5.2, R6.2, R7.1
unnamed: A1.10 (A1), J1.T, R10.1
unnamed: A1.11 (A2), J2.T, R11.1
unnamed: A1.12 (A3), J3.T, R12.1
unnamed: A1.19 (D4), JP1.1 (A)
unnamed: A1.22 (D7), R15.1
unnamed: A1.23 (D8), R16.1
unnamed: A1.24 (D9), R17.1
unnamed: A1.32 (SCL/A5), JP1.3 (B)
unnamed: C1.2, J2.G, R1.2, R5.1, R11.2
unnamed: C2.2, J3.G, R2.2, R6.1, R12.2
unnamed: C3.2, J1.G, R3.2, R4.1, R10.2
unnamed: D1.2 (A), R15.2
unnamed: D2.2 (A), R16.2
unnamed: D3.2 (A), R17.2

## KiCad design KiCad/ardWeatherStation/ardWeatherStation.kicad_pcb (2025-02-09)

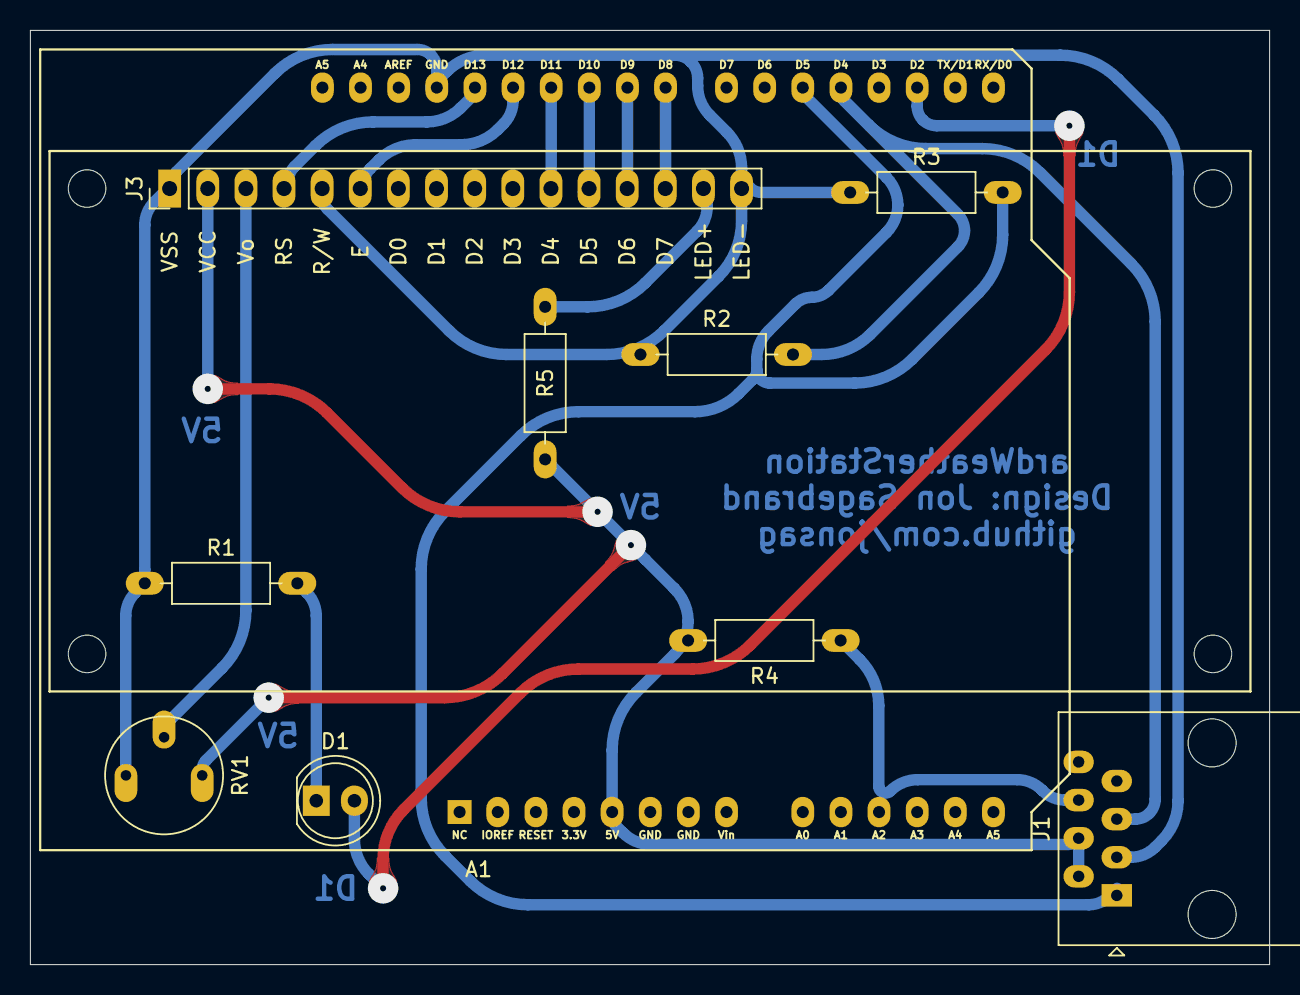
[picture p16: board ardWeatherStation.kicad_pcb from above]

Board: 2 copper layers, 82.6 x 62.2 mm, 10 parts (0 on the bottom side), 15 nets.

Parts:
A1: Arduino_UNO_R3; Arduino_UNO_R3_shield_large
D1: LED; LED_D5.0mm_large
J1: RJ45; RJ45_Amphenol_54602-x08_Horizontal_large
J3: 16-pin_LCD_header; LCD_HD44780_16x2_w_headers_large
R1, R5: 330R; R_Axial_DIN0207_L6.3mm_D2.5mm_P10.16mm_Horizontal_larger_pa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
R2, R3: 10k; R_Axial_DIN0207_L6.3mm_D2.5mm_P10.16mm_Horizontal_larger_pa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
R4: 15k; R_Axial_DIN0207_L6.3mm_D2.5mm_P10.16mm_Horizontal_larger_pa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
RV1: 10k; Potentiometer_Bourns_3339P_Vertical_large

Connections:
/+5V: A1.5 (+5V), J1.2, J1.4, J3.2 (VCC), R4.2, R5.2, RV1.3
/GND: A1.29 (GND), J1.3, J3.1 (VSS), J3.5 (R/W), J3.16 (LED-), R1.1, R2.1, R3.1, RV1.1
unnamed: A1.11 (A2), J1.6, R4.1
unnamed: A1.17 (D2), D1.2 (A)
unnamed: A1.19 (D4), J1.5, R2.2
unnamed: A1.20 (D5), J1.1, R3.2
unnamed: A1.23 (D8), J3.14 (D7)
unnamed: A1.24 (D9), J3.13 (D6)
unnamed: A1.25 (D10), J3.12 (D5)
unnamed: A1.26 (D11), J3.11 (D4)
unnamed: A1.27 (D12), J3.6 (E)
unnamed: A1.28 (D13), J3.4 (RS)
unnamed: D1.1 (K), R1.2
unnamed: J3.3 (Vo), RV1.2
unnamed: J3.15 (LED+), R5.1

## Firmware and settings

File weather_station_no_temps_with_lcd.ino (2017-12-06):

/*
 The circuit:
 *                             GND            display pin 1
 *  supply voltage for logic   +5V            display pin 2
 
 * 10K resistor:
 * ends to +5V and ground
 * LCD VO - contrast           wiper          display pin 3
 
 * LCD RS pin                  digital pin 13 display pin 4
 * LCD R/W pin                 GND            display pin 5
 * LCD Enable pin              digital pin 12 display pin 6
 * LCD D4                      digital pin 11 display pin 11
 * LCD D5                      digital pin 10 display pin 12
 * LCD D6                      digital pin 9  display pin 13
 * LCD D7                      digital pin 8  display pin 14
 
 * 10K resistor:
 * ends to +5V and ground
 * back light anode:+4.2V      wiper          display pin 15
 * back light cathode          wiper          display pin 16
 */

#include <Average.h> // add library for calculating averages
#include <LiquidCrystal.h>

// initialize the library with the numbers of the interface pins
LiquidCrystal lcd(13, 12, 11, 10, 9, 8);

// declare in/outputs
int simulateRainButton = 7;
int rain0Button = 6;
int anemometer = 5;
int rainBucket = 4;
// digital 3 reserved for 1-wire
int redLed = 2;
int vane = A2;

int anemometerState = 0;
int lastAnemometerState = 0;
int anemometerPulses = 0;
//int anemometerPulsesPerSecond = 0;
float windSpeed = 0; // the speed in m/s
float windSpeedAverage = 0; // the average speed in m/s
int windSpeedAverageCounter = 0;
/*
int beaufort = 0;
 char* windLabels[] = {
 "Calm", "Light air", "Light breeze", "Gentle breeze", "Moderate breeze", "Fresh breeze", "Strong breeze", "High wind, moderate gale, near gale", "Gale, fresh gale", "Strong gale", "Storm, whole gale", "Violent storm", "Hurricane force"};
 char* svWindLabels[] = {
 "Lugnt", "Svag vind", "Svag vind", "Måttlig vind", "Måttlig vind", "Frisk vind", "Frisk vind", "Hård vind", "Hård vind", "Mycket hård vind", "Storm", "Svår storm", "Orkan"};
 char* svWindLabelsAtSea[] = {
 "Stiltje, bleke", "Nästan stiltje", "Lätt (laber) bris", "God bris", "Frisk bris", "Styv bris", "Hård bris, frisk kuling/kultje", "Styv kuling/kultje", "Hård kuling/kultje", "Halv storm", "Storm", "Svår storm", "Orkan"};
 */

//int simulateRainButtonState = 0;
//int lastSimulateRainButtonState = 0;

//int rain0ButtonState = 0;
//int lastRain0ButtonState = 0;

int rainBucketState = 0;
int lastrainBucketState = 0;
int rainBucketTips = 0;
float totalRain = 0;
float rainSinceLastPoll = 0;
int rainIntensity = 0;

int vaneValue = 0;
int directionValue = 0;
char* vaneDirection[]={
  "NA", "E", "N", "W", "S", "NE", "NW", "SW", "SE", "ENE", "NNE", "NNW", "WNW", "WSW", "SSW", "SSE", "ESE"};
char* vaneDegrees[]={
  "NA", "90", "0", "270", "180", "45", "315", "225", "135", "67.5", "22.5", "337.5", "292.5", "247.5", "202.5", "157.5", "112.5"};
int vaneAverageCounter = 0;
#define vaneSamples 100
int vaneAverage[vaneSamples];
int displayedVaneAverage = 0;

unsigned long currentMillis = 000000; // will store millis()
unsigned long anemometerMillis = 000000;
unsigned long lastRainMillis = 000000;
unsigned long blinkMillis = 000000;
unsigned long serialPrintMillis = 000000;
unsigned long lcdPrintMillis = 000000;
unsigned long pollMillis = 000000;
unsigned long tickMillis = 000000;

boolean blinkRedLed = false; 
boolean redLedOn = false;
boolean polled = false;

int length1 = 0;
int length2 = 0;

byte byteRead; // stores data coming from serial

int tick = 0;
int lastTick = 0;

////////////////////////////// setup //////////////////////////////
void setup() {
  // set up the LCD's number of columns and rows:
  Serial.println("Initializing LCD...");
  lcd.begin(20, 4);
  // Print a message to the LCD.
  lcd.print("Booting...");

  delay(5000);
  Serial.begin(9600);
  Serial.println("weather_station_no_temps_with_lcd_140122");
  lcd.setCursor(0, 1);
  lcd.print("Started serial");
  Serial.println("Started serial communication after waiting 5 seconds");
  lcd.setCursor(0, 2);
  lcd.print("Waiting...");
  Serial.println("Waiting another 5 seconds...");
  delay(5000);  //important on linux a serial port can lock up otherwise

  // declare digital inputs
  lcd.setCursor(0, 2);
  lcd.print("Starting in/outputs...");
  Serial.println("Defining digital in/outputs...");
  //pinMode(simulateRainButton, INPUT);
  //pinMode(rain0Button, INPUT);
  pinMode(anemometer, INPUT);
  pinMode(rainBucket, INPUT);
  pinMode(redLed, OUTPUT);

  lcd.setCursor(0, 3);
  lcd.print("Starting now...");
  delay(1000);

  // print headlines to LCD
  Serial.println("Printing headlines to LCD");
  lcd.clear();
  lcd.setCursor(0, 2);
  lcd.print("Rain: ");
  lcd.setCursor(17, 1);
  lcd.print("m/s");
  Serial.println("Start!");


  Serial.println("Enter h for help");
}

////////////////////////////// main loop //////////////////////////////
void loop() {
  currentMillis = millis();

  ///////////////////////// read inputs
  //simulateRainButtonState = digitalRead(simulateRainButton);
  //rain0ButtonState = digitalRead(rain0Button);
  anemometerState = digitalRead(anemometer);
  rainBucketState = digitalRead(rainBucket);
  vaneValue = analogRead(vane);

  /*
  Serial.print("rain0Button: ");
   Serial.print(rain0ButtonState);
   Serial.print("     ");
   Serial.print("simulateRainButton: ");
   Serial.print(simulateRainButtonState);
   Serial.println();
   */

  ///////////////////////// vane - wind direction
  directionValue = windDirection();
  if (vaneAverageCounter >= vaneSamples) {
    displayedVaneAverage = mean(vaneAverage,vaneAverageCounter),DEC;
    vaneAverageCounter = 0;
  }
  else {
    vaneAverage[vaneAverageCounter] = atoi(vaneDegrees[directionValue]);
    vaneAverageCounter++;
  }

  ///////////////////////// anemometer - wind speed
  if(anemometerState != lastAnemometerState && anemometerState == HIGH) { // if we have recieved a pulse
    anemometerPulses++;
    blinkRedLed = true;
  }
  lastAnemometerState = anemometerState; // save state to next run

  if(currentMillis - anemometerMillis >= 10000) {
    //anemometerPulsesPerSecond = anemometerPulses;
    windSpeed = anemometerPulses * 0.667 / 10; // one pulse is 0.667 m/s
    anemometerPulses = 0;
    anemometerMillis = currentMillis;
    windSpeedAverage += windSpeed;
    windSpeedAverageCounter ++;
  }

  ///////////////////////// rain gauge - tip bucket
  if(rainBucketState != lastrainBucketState && rainBucketState == HIGH) { // if we have recieved a pulse
    rainBucketTips++;
    totalRain += 0.279; // one pulse is 0.279 mm of rain
    rainSinceLastPoll += 0.279;
    rainIntensity = 60 * 0.279 / ((currentMillis - lastRainMillis) / 1000);
    lastRainMillis = currentMillis;
    blinkRedLed = true;     
  }  
  lastrainBucketState = rainBucketState; // save state for next run

  if((currentMillis - lastRainMillis) > 60000) { // if we haven't recieved a puse for 60 seconds, set intensity to 0
    rainIntensity = 0;
  }

  ///////////////////// check if reset rain meter button is pressed
  /* if (rain0ButtonState != lastRain0ButtonState) {
   if (rain0ButtonState == HIGH) {
   Serial.println("Resetting rain meter");
   totalRain = 0;
   //blinkRedLed = true;
   }
   }
   lastRain0ButtonState = rain0ButtonState;
   */

  ///////////////////// check serial for message
  if (Serial.available()) { // check if data has been sent from the computer
    byteRead = Serial.read(); // read the most recent byte
    if ( byteRead == 99 ) { // c outputs complete information
      serialPrintComplete();
    }
    else if ( byteRead == 104 ) { // h outputs help info
      help();
    }
    else if ( byteRead == 112 ) { // p does a poll
      poll();
    }
    else if ( byteRead == 101 ) { // e explains polling output
      explain();
    }
    /*
    else if ( byteRead == 115 ) { // s simulates rain
     totalRain += 0.279; // one pulse is 0.279 mm of rain
     rainSinceLastPoll += 0.279;
     }
     */
    else if ( byteRead == 114 ) { // r resets rain since last poll
      resetAll();
    }
    /*
     else if ( byteRead == 82 ) { // R resets rain total
     totalRain = 0;
     }
     */
    else {
      Serial.write(byteRead);
      Serial.println(" NA");
    }
  }

  ///////////////////// blink
  if (blinkRedLed || redLedOn) { // if we should light led or if it's already lit
    rainBlinking();
  }

  ///////////////////// print
  lcdPrint();

  ///////////////////// erase status line
  if (currentMillis - pollMillis >= 1000 ) {
    lcd.setCursor(0, 3);
    lcd.print("                    ");
  }

  ///////////////////// life tick
  tickPrint();

} // end of main loop

////////////////////////////// evaluate wind direction //////////////////////////////
int windDirection(void) {
  if(vaneValue >= 0 && vaneValue <= 50) { // ESE
    directionValue = 16;
  }
  else if(vaneValue >= 51 && vaneValue <= 59) { // ENE
    directionValue = 9;
  }
  else if(vaneValue >= 60 && vaneValue <= 75) { // E
    directionValue = 1;
  }
  else if(vaneValue >= 76 && vaneValue <= 115) { // SSE
    directionValue = 15;
  }
  else if(vaneValue >= 116 && vaneValue <= 155) { // SE
    directionValue = 8;
  }
  else if(vaneValue >= 156 && vaneValue <= 190) { // SSW
    directionValue = 14;
  }
  else if(vaneValue >= 191 && vaneValue <= 270) { // S
    directionValue = 4;
  }
  else if(vaneValue >= 271 && vaneValue <= 335) { // NNE
    directionValue = 10;
  }
  else if(vaneValue >= 336 && vaneValue <= 450) { // NE
    directionValue = 5;
  }
  else if(vaneValue >= 451 && vaneValue <= 510) { // WSW
    directionValue = 13;
  }
  else if(vaneValue >= 511 && vaneValue <= 570) { // SW
    directionValue = 7;
  }
  else if(vaneValue >= 571 && vaneValue <= 660) { // NNW
    directionValue = 11;
  }
  else if(vaneValue >= 661 && vaneValue <= 730) { // N
    directionValue = 2;
  }
  else if(vaneValue >= 731 && vaneValue <= 805) { // WNW
    directionValue = 12;
  }
  else if(vaneValue >= 806 && vaneValue <= 870) { // NW
    directionValue = 6;
  }
  else if(vaneValue >= 871 && vaneValue <= 1023) { // W
    directionValue = 3;
  }
  else {
    directionValue = 0;
  }
  return directionValue;
}

/////////////////////////////// blinking rain LED ///////////////////////////////
void rainBlinking(void) {
  if (redLedOn && blinkMillis - currentMillis >= 200) {
    digitalWrite(redLed, LOW);
    redLedOn = false;
  }
  else if(blinkRedLed) {
    digitalWrite(redLed, HIGH);
    blinkMillis = currentMillis;
    blinkRedLed = false;
    redLedOn = true;
  }
}

/////////////////////////////// print  complete output to serial ///////////////////////////////
void serialPrintComplete(void) {
  if(currentMillis - serialPrintMillis >= 1000) {
    //Serial.print(currentMillis);
    //Serial.print("    ");

    //Serial.print(vaneValue);
    //Serial.print("    ");
    Serial.print("Wind direction: ");
    Serial.print(vaneDirection[directionValue]);
    Serial.print("    ");
    Serial.print(vaneDegrees[directionValue]);
    Serial.print("    ");

    //Serial.print(anemometerState);
    //Serial.print("    ");
    //Serial.print(anemometerPulsesPerSecond);
    //Serial.print("    ");
    Serial.print("Wind speed: ");
    Serial.print(windSpeed);
    Serial.print(" m/s    ");
    Serial.print("Average wind speed: ");
    if(windSpeedAverageCounter != 0) {
      Serial.print(windSpeedAverage / windSpeedAverageCounter);
    }
    else {
      Serial.print(windSpeedAverage);
    }
    Serial.print(" m/s    ");
    Serial.print(",");
    Serial.print("Rain intensity: ");
    Serial.print(rainIntensity);
    Serial.print(" mm/min    ");
    //Serial.print(rainBucketState);
    //Serial.print("    ");
    //Serial.print(rainBucketTips);
    //Serial.print("    ");
    Serial.print("Rain total: ");
    Serial.print(totalRain);
    Serial.print(" mm    ");
    //Serial.print(currentMillis - lastRainMillis);
    //Serial.print("    ");

    Serial.println();

    //serialPrintMillis = currentMillis;
  }
}

/////////////////////////////// print to LCD ///////////////////////////////
void lcdPrint(void) {
  //lcd.setCursor(0, 0);
  //lcd.print(currentMillis);

  if(currentMillis - lcdPrintMillis >= 1000) {
    ///// print wind
    lcd.setCursor(0, 1);
    lcd.print("   ");
    lcd.setCursor(0, 1);
    lcd.print(vaneDirection[directionValue]);

    //length = getLength(vaneDirection[directionValue]);
    lcd.setCursor(4, 1);
    lcd.print("   ");
    length1 = getLength(displayedVaneAverage);
    lcd.setCursor(7 - length1, 1);
    lcd.print(displayedVaneAverage);

    lcd.setCursor(7, 1);
    lcd.print((char)223);

    lcd.setCursor(12, 1);
    //windSpeed = 8.43;
    lcd.print(windSpeed);
    //length = 3 + getLength(windSpeed);

    ///// print rain
    lcd.setCursor(6, 2);
    lcd.print(totalRain);

    lcdPrintMillis = currentMillis;
  }
}

/////////////////////////////// get length ///////////////////////////////
int getLength(int value) { 
  int length;

  if(value > 9999)
    length = 5;
  else if(value > 999)
    length = 4;
  else if(value > 99)
    length = 3;
  else if(value > 9)
    length = 2;
  else
    length = 1;

  return length;
}

/////////////////////////////// help ///////////////////////////////
void help(void) {
  Serial.println("---------- help ----------");
  Serial.println("Enter c for complete output");
  Serial.println("Enter p to simulate a poll");
  Serial.println("Enter e to explane poll output");
  //Serial.println("Enter s to simulate rain");
  Serial.println("Enter r to reset rain since last poll");
  //Serial.println("Enter R to reset rain total");
  Serial.println("Enter h for this help");
  Serial.println("--------------------------");
}

/////////////////////////////// explain ///////////////////////////////
void explain(void) {
  Serial.print("pollStart");
  Serial.print(",");
  Serial.print("Wind direction");
  Serial.print(",");
  Serial.print("Wind direction degrees");
  Serial.print(",");
  Serial.print("Average wind direction degrees");
  Serial.print(",");
  Serial.print("Wind speed");
  Serial.print(",");
  Serial.print("Average wind speed");
  Serial.print(",");
  Serial.print("Rain since last poll");
  Serial.print(",");
  //Serial.print("Rain intensity");
  //Serial.print(",");
  Serial.print("pollEnd");
  Serial.println();
}

/////////////////////////////// poll ///////////////////////////////
void poll(void) {
  polled = true;
  lcd.setCursor(0, 3);
  lcd.print("Polled from serial");

  Serial.print("pollStart");
  Serial.print(",");
  Serial.print(vaneDirection[directionValue]);
  Serial.print(",");
  Serial.print(vaneDegrees[directionValue]);
  Serial.print(",");
  Serial.print(displayedVaneAverage);
  Serial.print(",");
  Serial.print(windSpeed);
  Serial.print(",");
  if(windSpeedAverageCounter != 0) {
    Serial.print(windSpeedAverage / windSpeedAverageCounter);
  }
  else {
    Serial.print(windSpeedAverage);
  }
  Serial.print(",");
  Serial.print(rainSinceLastPoll);
  Serial.print(",");
  //Serial.print(rainIntensity);
  //Serial.print(",");
  Serial.print("pollEnd");
  Serial.println();
  pollMillis = currentMillis;
}

/////////////////////////////// tick on lcd ///////////////////////////////
void tickPrint(void) {
  if(currentMillis - tickMillis > 2000) {
    tickMillis = currentMillis;
  }

  if(currentMillis - tickMillis > 1000) {
    tick = 219;
  }
  else {
    tick = 165;
  }

  if(tick != lastTick) {
    lcd.setCursor(19, 0);
    lcd.print((char)tick);
    //lcd.print(tick);
  }
  lastTick = tick;
}

/////////////////////////////// reset values after poll ///////////////////////////////
void resetAll(void) {
  rainSinceLastPoll = 0;
  windSpeedAverage = 0;
  windSpeedAverageCounter = 0;
  Serial.println("Values reset");
}

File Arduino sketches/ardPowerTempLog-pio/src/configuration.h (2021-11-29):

String programName = "ardCurrentTempLog";
String date = "20200221";
String author = "Jon Sagebrand";
String email = "jonsagebrand@gmail.com";

/*
  Define these variables down in the code:
  ------------------------------------
  byte mac[] = -----the hex numbers on the sticker on your ethernet shield
  IPAddress ip( ----- the IP number you want yor arduino board to use
  if ( pollAge > 600000 ----- how long is the intervals between automatic reset of puls counting, milliseconds
  if (!tempsRead || tempAge > 60000 -----how often should we reset temps, milliseconds

  intervals - millis() - milliseconds:
  ------------------------------------
  10 seconds = 10000
  1 min = 60000
  5 min = 300000
  10 min = 600000
  1 hour = 3600000
  1 day = 86400000
  1 week = 604800000

  LEDs
  ------------------------------------
  YELLOW - discovering or reading temp sensors
  GREEN - activity on internet interface
  RED - pulse received
*/

#include <Arduino.h>

#include <SPI.h> // ethernet libraries
#include <Dhcp.h>
#include <Dns.h>
#include <Ethernet.h>
#include <EthernetServer.h>
//#include <EthernetUdp.h>
//#include <OneWire.h> // oneWire libraries
//#include <DallasTemperature.h>
//#include <util.h>
//#include <Time.h> // time library

/*******************************
  Ethernet settings
*******************************/
byte mac[] = {
    0x90, 0xA2, 0xDA, 0x0C, 0x00, 0x76}; // MAC address, printed on a sticker on the shield
IPAddress ip(192, 168, 10, 10);          // ethernet shields wanted IP
//IPAddress gateway(192,168,10,1); // internet access via router
//IPAddress subnet(255,255,255,0); //subnet mask
EthernetServer server(80); // this arduinos web server port
String readString;         // string read from servers interface

/*******************************
  OneWire settings
*******************************/
/*#define ONE_WIRE_BUS 2 // oneWire bus bin
  OneWire oneWire(ONE_WIRE_BUS); // setup oneWire instance to communicate with any OneWire devices
  DallasTemperature sensors(&oneWire); // pass our oneWire reference to Dallas Temperature
  byte numberOfSensors; // will store how many sensors we have
  float tempValue[] = { // will store the temps
  0, 1, 2, 3
  };
  boolean tempsRead = false; // will be true after first temp reading
  byte present = 0;
  byte data[12];
  byte addr[8];
  byte count = 0;*/

/*******************************
  Pin numbers
*******************************/
const int pinPulse = 4; // number of the pin connected to the photo transistor
//const int yellowPinTemp =  7;      // number of the yellow LED pin, status
const int greenPinNetwork = 8; // number of the green LED pin, polled
const int redPinPulse = 9;     // number of the red LED pin, pulse received

/*******************************
  Current clamps inputs
*******************************/
const int phase[] = {
    A1, A2, A3};

/*******************************
  Current values variables
*******************************/
double currentReading;

double displayedCurrent[] = { // the displayed value on the web page
    1, 2, 3};
double ackDisplayedCurrent[] = { // all reads accumulated
    1, 2, 3};
double polledCurrent[] = { // the average current between each poll
    1, 2, 3};
double ackPolledCurrent[] = { // all averages accumulated
    1, 2, 3};

int readAverageCounter = 200; // counter for how many readings should be averaged

/*******************************
  Misc variables
*******************************/
int pulseButtonState = 0;     // variable for reading pulse button status
int lastPulseButtonState = 0; // saves pulse buttons previous state
byte pulseState = 0;
int lastPulseState = 0;
int syncButtonState = 0; // variable for reading sync button status

//int ledStateYellow = LOW; // ledState holds the LED outputs
int ledStateGreen = LOW;
int ledStateRed = LOW;

boolean blinkRed = false; // blink the LEDs
boolean blinkGreen = false;
//boolean blinkYellow = false;

int blinkRedCounter = 0; // counters for blinks of the LEDs
int blinkGreenCounter = 0;
//int blinkYellowCounter = 0;
int blinkYellowOffCounter = 0;

/*******************************
  Times variables
*******************************/
unsigned long currentMillis = 000000; // will store millis()

unsigned long pollMillis = 000000; // will store last time resetInterval was reset
unsigned long pollAge = 000000;    // how long since last poll

//unsigned long tempsMillis = 000000; // will store last time temps was read
//unsigned long tempAge = 000000; // how long since the temps was read

unsigned int pulsesLastPoll = 0; // various pulse counters, 1 pulse = 1/1000 kwh
unsigned int pulses = 0;
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

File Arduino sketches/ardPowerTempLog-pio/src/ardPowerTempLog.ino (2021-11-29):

#include "configuration.h" // sets all variables
//#include "OneWireDiscover.h"
#include "blink.h"
//#include "getTemps.h"
#include "readCurr.h"
#include "webPage.h"

//////////////////////////////////// setup ////////////////////////////////////
void setup()
{
  /*******************************
    Start serial
  *******************************/
  Serial.begin(9600);

  Serial.println();
  Serial.println("---------- Starting ----------");
  Serial.println(programName); // print information
  Serial.println(date);
  Serial.print("by ");
  Serial.println(author);
  Serial.println(email);
  Serial.println();

  Serial.println("Started serial communication");
  Serial.println();

  /*******************************
    Start in- outputs
  *******************************/
  Serial.println("Initiating in/outputs...");
  pinMode(pinPulse, INPUT);
  //pinMode(yellowPinTemp, OUTPUT); // initialize the LED pins as outputs
  pinMode(greenPinNetwork, OUTPUT);
  pinMode(redPinPulse, OUTPUT);
  Serial.println();

  /*******************************
    Start 1-wire
  *******************************/
  /*Serial.println("Starting 1-wire sensors...");
    sensors.begin(); // start up the oneWire library
    Serial.println();

    Serial.println("Discovering and counting sensors...");
    numberOfSensors = discoverOneWireDevices(); // count sensors
    Serial.println();*/

  /*******************************
    Wait for stability
  *******************************/
  Serial.println("Waiting 5 seconds...");
  delay(5000); //important on linux a serial port can lock up otherwise
  Serial.println();

  /*******************************
    Start ethernet
  *******************************/
  Serial.print("Starting ethernet with IP: ");
  Serial.print(ip);
  Serial.println(" ...");
  Ethernet.begin(mac, ip);
  Serial.println();

  /*******************************
    Start webserver
  *******************************/
  Serial.println("Starting web server...");
  server.begin(); //start arduinos web server
  Serial.println();

  /*******************************
    Finished starting
  *******************************/
  Serial.println("Starting...");
  Serial.println();
}

/*******************************
  Main
*******************************/
void loop()
{
  /*******************************
    Check some times
  *******************************/
  currentMillis = millis();               // millis right now
  pollAge = (currentMillis - pollMillis); // how much time elapsed since last log write
  //tempAge = (currentMillis - tempsMillis); // how much time elapsed since last temp reading

  /*******************************
    Read digital inputs
  *******************************/
  pulseState = digitalRead(pinPulse); // read pulse input

  /*******************************
    Read analog values
  *******************************/
  //if (!readTemps) {
  readCurrents();
  //}

  /*******************************
    Check for pulse
  *******************************/
  if (pulseState != lastPulseState)
  { // light red LED if button is pressed
    if (pulseState == HIGH)
    {           // if the current state is HIGH then the button went from off to on
      pulses++; // +1 on puls counter
      Serial.print("Pulse received, pulses this interval is now ");
      Serial.println(pulses);
      blinkRed = true;
    }
  }
  lastPulseState = pulseState; // save pulse button state till next loop

  /*******************************
    Check if it's time to reset pulses
  *******************************/
  if (pollAge > 600000)
  {
    pollMillis = currentMillis;
    Serial.println("---Resetting pulses");
    pulsesLastPoll = pulses;
    pulses = 0;
  }

  /*******************************
    Check if it's time to read temps
  *******************************/
  /*if (!tempsRead || tempAge > 60000) { // read temperatures if we haven't before, or if it's time to do so
    readTemps = true;
    getTemperatures();
    }*/

  /*******************************
    Blink LEDs
  *******************************/
  blinkLEDs();

  /*******************************
    Web server
  *******************************/
  presentWebPage();

} // end of main loop

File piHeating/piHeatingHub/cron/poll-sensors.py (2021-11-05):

#!/usr/bin/env python

import MySQLdb
import datetime
import urllib.request, urllib.error, urllib.parse
import os

try:
    from configparser import ConfigParser
except ImportError:
    from configparser import ConfigParser

config = ConfigParser()
config.read("/home/pi/bin/piHeatingHub/config/config.ini")

servername = config.get("db", "server")
username = config.get("db", "user")
password = config.get("db", "password")
dbname = config.get("db", "database")

t = datetime.datetime.now().strftime("%s")

cnx = MySQLdb.connect(host=servername, user=username, passwd=password, db=dbname)
cnx.autocommit(True)
cursorread = cnx.cursor()
query = "SELECT id, ref, ip FROM sensors"
cursorread.execute(query)
results = cursorread.fetchall()
cursorread.close()
cnx.close()

for i in results:
    sensor_id = i[0]
    sensor_ref = i[1]
    sensor_ip = i[2]

    sensor_url = "http://" + sensor_ip + ":8081/value.php?id=" + sensor_ref

    print(sensor_url)

    try:
        data = float(urllib.request.urlopen(sensor_url).read())
    except:
        data = "NULL"

    print(data)
    print(sensor_id)

    sql = (
        "UPDATE sensors SET value=" + str(data) + " WHERE id='" + str(sensor_id) + "';"
    )

    print(sql)

    # cursorwrite.execute( sql )

    try:
        cnx = MySQLdb.connect(
            host=servername, user=username, passwd=password, db=dbname
        )
        cnx.autocommit(True)
        cursorwrite = cnx.cursor()
        cursorwrite.execute(sql)

        print(("affected rows = {}".format(cursorwrite.rowcount)))

        cursorwrite.close()
        cnx.close()

        # rows = cur.fetchall()
    except MySQLdb.Error as e:
        try:
            print("MySQL Error [%d]: %s" % (e.args[0], e.args[1]))
        except IndexError:
            print("MySQL Error: %s" % str(e))

    print("database done")

    filename = "/home/pi/bin/piHeatingHub/data/s-" + str(sensor_id) + ".rrd"

    print(filename)

    if not os.path.exists(filename):
        print((os.path.exists(filename)))
        os.system(
            "/usr/bin/rrdtool create "
            + filename
            + " --step 60 \
      --start now \
      DS:data:GAUGE:120:U:U \
      RRA:MIN:0.5:1:10080 \
      RRA:MIN:0.5:5:51840 \
      RRA:MIN:0.5:60:8760 \
      RRA:AVERAGE:0.5:1:10080 \
      RRA:AVERAGE:0.5:5:51840 \
      RRA:AVERAGE:0.5:60:8760 \
      RRA:MAX:0.5:1:10080 \
      RRA:MAX:0.5:5:51840 \
      RRA:MAX:0.5:60:8760"
        )

    if data != "NULL":
        print("rrd")
        os.system(
            "/usr/bin/rrdtool update " + filename + " " + str(t) + ":" + str(data)
        )

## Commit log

2017-12-06 Second batch of files
    [ArduinoLogger.sch, Average wind direction.xlsx, data.csv]
2017-12-08 Renamed and included pi-heating-weather
    [data.csv]
2017-12-08 Added install for pi-heating-weather
    [data.csv]
2017-12-08 Correcting pi-heating-weather
    [data.csv]
2017-12-09 Renamed some things
    [data.csv]
2017-12-09 temperature.php and tempPoller.php now works
2017-12-13 Tinkered with temperature.php
2017-12-15 now prints tempdata and draws temp chart
2017-12-17 Now polling power
2017-12-17 now draws current chart
2017-12-18 Now draws power/temp chart
2017-12-18 Added sketch for power measurements on arduino
2017-12-18 Added stuff and moved other stuff around
    [ArduinoLogger.sch]
2017-12-19 Started working on weather
    [Average wind direction.xlsx]
2017-12-21 Now logs and prints weather data
2018-01-05 Sensors list now shows graph
2018-01-05 Cleaning up
    [data.csv]
2018-01-11 Fixed port bug when polling temps
    [poll-sensors.py]
2018-01-11 Button lights up LCD
2018-01-13 Switched to symlinks for gpio
2018-01-13 Added buttons 2,3 and 4
2018-01-16 4 buttons work
2018-01-28 LCD now prints degree sign
2018-02-20 Updated Arduino Logger sketch
    [ArduinoLogger.sch]
2018-11-25 Added script to calculate ideal burden resisto for the CT sensor
2018-12-06 Updated Readme. Added small scripts for calculating burden resistor when measuring currents for power logging.
2020-02-09 added KiCad
    [ardPowerTempLog.kicad_pcb, ardPowerTempLog.sch]
2020-02-21 added text
    [ardPowerTempLog.sch]
2020-02-22 added new arduino sketch for current temp logging
    [configuration.h]
2020-02-22 added sub project, moved stuff around
    [configuration.h]
2020-02-22 added powerTempLog
2020-02-22 added older powertemplog
    [data.csv]
2020-02-22 many changes
    [data.csv]
2020-02-23 cleaned up
    [ArduinoLogger.sch, ardPowerTempLog no peripherals routed1 by freerouting copper pour.kicad_pcb, ardPowerTempLog no peripherals routed1 by freerouting.kicad_pcb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]
2020-02-25 pi heating remote updates
2020-02-27 added schematcs and pcb, changed gpio
    [piHeatingRPi1.kicad_pcb, piHeatingRPi1.sch]
2020-02-29 kicad for rpi1
    [piHeatingRPi1.kicad_pcb]
2020-03-01 better cad
    [piHeatingRPi1.kicad_pcb, piHeatingRPi1.sch]
2020-03-01 more deletes
    [ardPowerTempLog no peripherals routed1 by freerouting copper pour.kicad_pcb, ardPowerTempLog no peripherals routed1 by freerouting.kicad_pcb, ardPowerTempLog n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]
2020-03-01 moved LCD files
    [piHeatingRPi1.kicad_pcb, piHeatingRPi1.sch]
2020-03-07 updated kicad
    [piHeatingRPi1.kicad_pcb, piHeatingRPi1.sch]
2020-03-09 added resistor value in kicad
    [piHeatingRPi1.sch]
2020-03-09 added more kicad files
2020-03-09 moved dallas from 5V to 3.3V
    [piHeatingRPi1.kicad_pcb, piHeatingRPi1.sch]
2020-03-14 changed www installation path (once again...)
    [piHeatingRPi1.kicad_pcb]
2020-03-15 LCD now working, started work on powerTempLog
2020-03-15 now prints tables, power and temp charts, not all powertemp chart
2020-03-15 currents and powertemp chart, csv working
2020-03-16 started work on ardWeatherStation
    [ardWeatherStation.sch]
2020-03-16 KiCad start
    [ardWeatherStation.sch]
2020-03-17 arduino weather
    [configuration.h]
2020-03-17 kicad: connector for weather sensors
    [ardWeatherStation.sch]
2020-03-18 kicad weather meters
    [ardWeatherStation.sch]
2020-03-18 kicad weather
    [ardWeatherStation.kicad_pcb, ardWeatherStation.sch]
2020-03-18 kicad, PCB
    [ardWeatherStation.kicad_pcb]
2020-03-22 weather sketch updates
    [ardWeatherStation.sch]
2020-03-22 weather sketch
    [configuration.h]
2020-03-24 piWeather working
    [ardWeatherStation.sch, configuration.h]
2020-03-29 bug when creating crons, moved around documentation
    [Average wind direction.xlsx, ardPowerTempLog.kicad_pcb, ardPowerTempLog.sch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]
2020-03-29 moved around sketches
    [configuration.h]
2020-03-29 updated powerTempLog sketch
2020-04-01 removed temp reading from ardPowerTempLog
    [configuration.h]
2020-07-09 added sketch to discover dallas 1-wire devices (DS18B20)
2020-07-11 now displays values for pi heating hub
2021-11-08 Update README.md
    https://forum.kicad.info/t/warning-avoid-all-links-to-kicad-pcb-org-use-kicad-org/31521
2021-11-29 Creaated PlatformIO projects
    [configuration.h]
2021-11-29 Deleted old sketches
    [configuration.h]
2022-05-14 ardPowerTempLog schematics
    [ardPowerTempLog.kicad_pcb, ardPowerTempLog.kicad_sch, ardPowerTempLog.sch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]
2022-05-14 kicad ardWeatherStation
    [ardWeatherStation.kicad_pcb, ardWeatherStation.kicad_sch, ardWeatherStation.sch]
2022-05-16 Rasp n moves
    [ardPowerTempLog.kicad_pcb, ardPowerTempLog.kicad_sch, ardWeatherStation.kicad_pcb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]
2025-02-09 kicad v8
    [ardPowerTempLog-smd.kicad_pcb, ardPowerTempLog-smd.kicad_sch, ardPowerTempLog.kicad_pcb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]
